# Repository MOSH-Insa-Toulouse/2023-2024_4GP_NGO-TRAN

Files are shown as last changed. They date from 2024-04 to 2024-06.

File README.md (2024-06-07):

# 2023-2024 : Capteur low-tech Graphite (Tan Anh Khoa NGO &amp; Le Duc Minh TRAN)

## SOMMAIRE
*** 
  - [Contexte](#contexte)
  - [Livrables](#livrables)
  - [Matériel nécessaire](#matériel-nécessaire)
  - [1. Simulation électronique du capteur sous LTSpice](#simulation-électronique-du-capteur-sous-ltspice)
  - [2. Design du PCB sous KiCad](#design-du-pcb-sous-kicad)
  - [3. Code arduino](#code-arduino)
  - [4. Application android APK sous MIT App Inventor](#application-android-apk-sous-mit-app-inventor)
  - [5. Réalisation du shield](#réalisation-du-shield)
  - [6. Banc de test](#banc-de-test)
  - [7. Datasheet](#datasheet)
  - [Contact](#contact) 

*** 

## Contexte
&nbsp;&nbsp;&nbsp;&nbsp;&nbsp;&nbsp;Dans le cadre de l'unité de formation "Du capteur au banc de test" dispensée en 4ème année du cursus Génie Physique à l'INSA Toulouse, notre équipe a conçu un dispositif de mesure de contrainte innovant. L'inspiration pour le capteur de ce dispositif provient de l'article scientifique "Pencil Drawn Strain Gauges and Chemiresistors on Paper" (Cheng-Wei Lin*, Zhibo Zhao*, Jaemyung Kim & Jiaxing Huang). Ce capteur, d'une simplicité remarquable, est constitué d'un morceau de papier sur lequel du graphite est appliqué à l'aide d'un crayon à papier. 

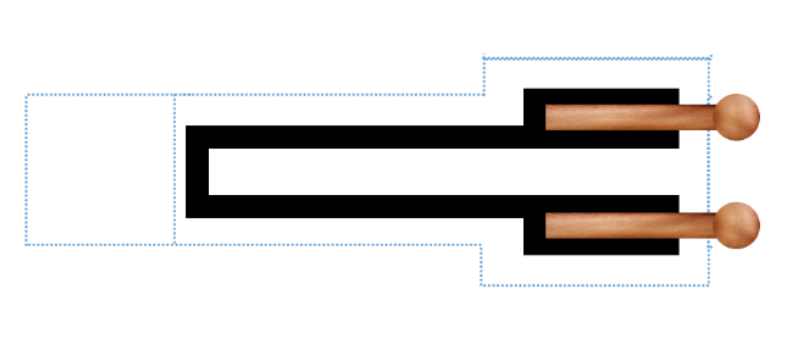
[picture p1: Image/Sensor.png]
capteur_graphite


&nbsp;&nbsp;&nbsp;&nbsp;&nbsp;&nbsp;Le principe de fonctionnement repose sur l'observation que la déformation du papier entraîne une variation du nombre de particules de graphite interconnectées. Cette modification de la structure granulaire du graphite se traduit par une variation de la résistance et de la conductance du capteur. En exploitant cette propriété, il devient possible de remonter à la déformation subie, à l'instar d'une jauge de contrainte classique.

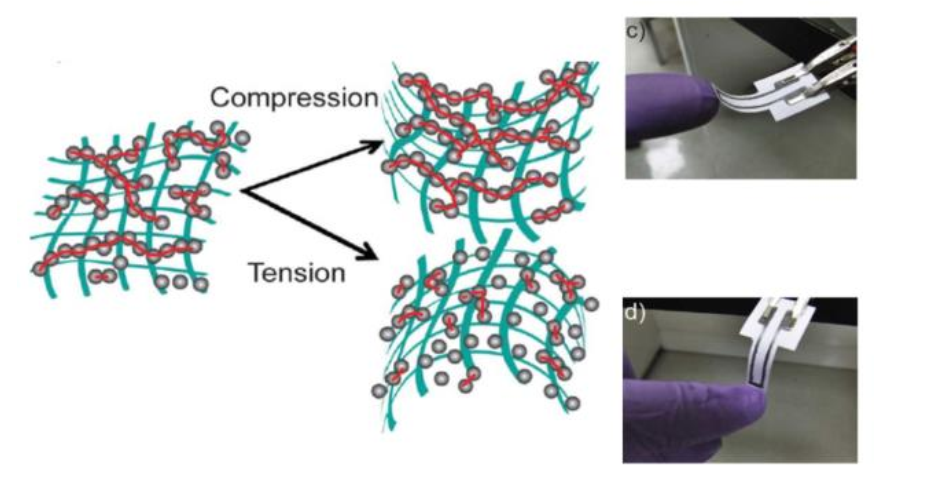
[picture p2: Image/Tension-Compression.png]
Tension-compression


&nbsp;&nbsp;&nbsp;&nbsp;&nbsp;&nbsp;Notre objectif principal était de développer un dispositif de mesure de déformation basé sur un capteur low-tech. Pour atteindre cet objectif, nous avons suivi une démarche structurée comprenant plusieurs étapes clés : simulations électroniques pour valider le concept, conception du circuit imprimé (PCB) pour intégrer le capteur, développement du code Arduino pour l'acquisition et le traitement des données, et enfin, réalisation de la fiche technique du dispositif.

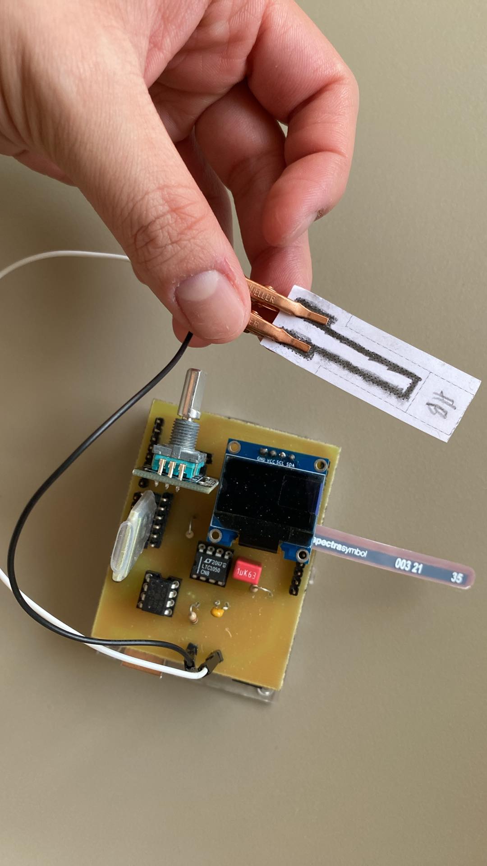
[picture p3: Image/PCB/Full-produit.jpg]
Full-produit


## Livrables
Les livrables de ce projet sont les suivants :
  
* Un shield PCB personnalisé connecté à une carte Arduino UNO. Ce shield intègre :
     
   - Un capteur de contrainte innovant à base de graphite.
   - Un amplificateur à transimpédance pour traiter le signal du capteur.
   - Un module Bluetooth pour la communication sans fil.
   - Un écran OLED pour l'affichage des données (ajouté pour améliorer l'expérience utilisateur).
   - Un capteur de flexion commercial pour comparaison (ajouté à des fins de validation).
   - Un potentiomètre numérique pour ajuster le gain de l'amplificateur (ajouté pour plus de flexibilité).
   - Un encodeur rotatif pour basculer entre les mesures des capteurs (ajouté pour faciliter la comparaison).
  
* Code Arduino     
   - L'acquisition des mesures de contrainte du capteur graphite.
   - La connexion et la communication Bluetooth.
   - L'affichage des données sur l'écran OLED.
   - Le réglage du gain via le potentiomètre numérique.
   - La sélection du capteur actif avec l'encodeur rotatif.
   - Réaliser des essais de banc de test rigoureux.
   - Évaluer les performances du capteur de contrainte graphite.
  
* Une application Android intuitive (APK) (développée avec MIT App Inventor) qui :
   - Permet de visualiser les données en temps réel.
   - Offre une interface conviviale pour interagir avec le système.

* Une datasheet complète qui détaille :
   - Les caractéristiques techniques du capteur graphite.
   - Son principe de fonctionnement.
   - Les instructions d'utilisation et de calibration.
   - Les résultats des tests de performance.

## Matériel nécessaire
Pour réaliser notre dispositif électronique, voici la liste des composants nécessaires :

- Résistances : 1 de 1 $k\ohm$, 1 de $10k\ohm$, 2 de $100k\ohm$ pour l'amplificateur transimpédance. 3 de $10k\ohm$ pour les boutons (peuvent être éviter en utilisant les résistances internes de l'arduino) et 1 de $33k\ohm$ pour le flex sensor.
- Capacités : 3 de 100 nF, 1 de 1 uF
- Arduino Uno
- Amplificateur opérationnel LTC1050
- Potentiomètre digital MCP41050
- Module Bluetooth HC05
- Ecran OLED 128x64
- Flex Sensor
- Encodeur rotatif KY-040

## Simulation électronique du capteur sous LTSpice
&nbsp;&nbsp;&nbsp;&nbsp;&nbsp;&nbsp;Pour amplifier le signal de notre capteur de graphite, caractérisé par une résistance élevée et un courant de sortie faible, nous avons conçu un montage à transimpédance. Ce montage, basé sur un amplificateur opérationnel (AOP), permet de convertir le faible courant en une tension exploitable par le convertisseur analogique-numérique (ADC) de l'Arduino UNO. \
&nbsp;&nbsp;&nbsp;&nbsp;&nbsp;&nbsp;La conception du circuit a été simulée sur LTspice, en suivant un [schéma spécifique](Image/LTspice/schema_suggere.png). Le choix de l'AOP s'est porté sur le LTC 1050, reconnu pour sa capacité à gérer des courants d'entrée faibles et son faible offset de tension, garantissant ainsi la précision des mesures. Voici son schéma :

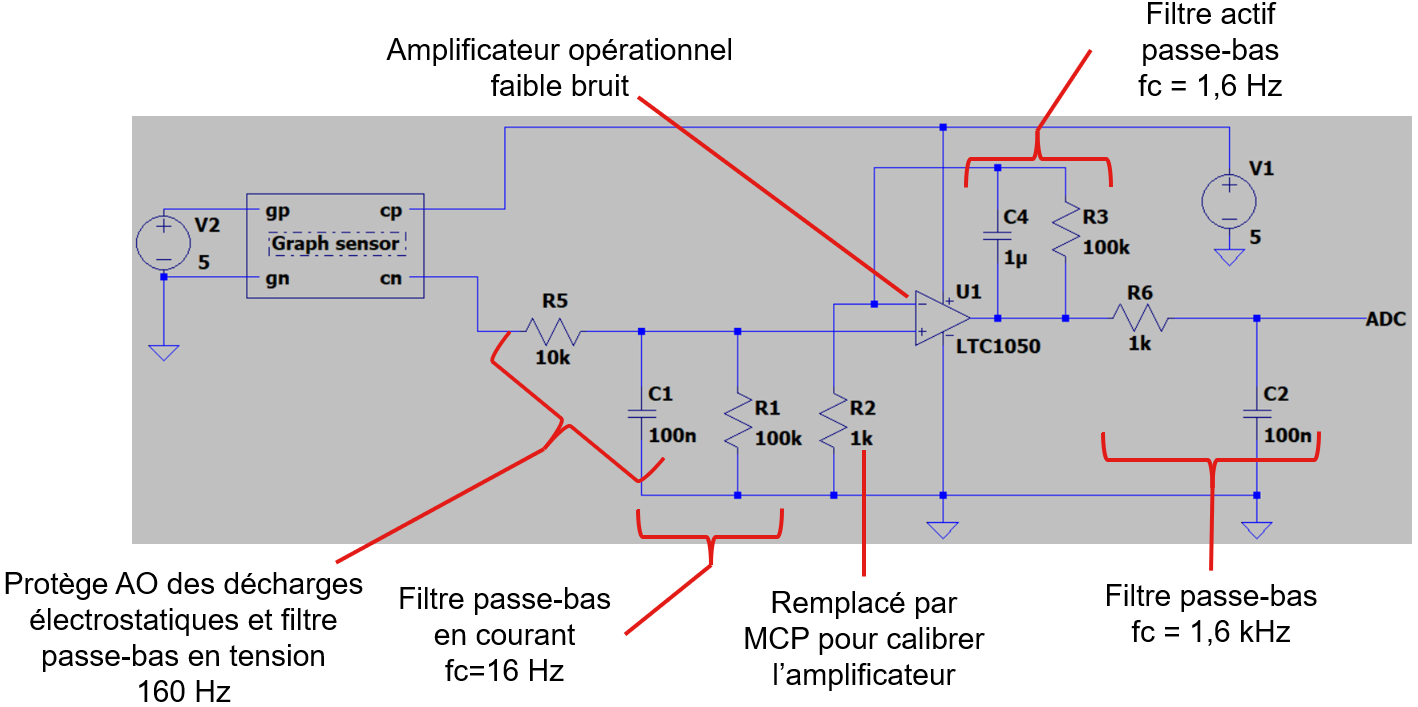
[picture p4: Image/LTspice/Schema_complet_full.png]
electronic-circuit


Afin d'optimiser la qualité du signal, trois filtres ont été intégrés au circuit :

- Un filtre passe-bas passif (R1, C1) à l'entrée, avec une fréquence de coupure de 16 Hz, pour atténuer les bruits en courant.
- Un filtre passe-bas actif (R3, C4) couplé à l'AOP, avec une fréquence de coupure de 1,6 Hz, pour filtrer le bruit à 50 Hz du réseau électrique.
- Un filtre passe-bas (R6, C2) à la sortie de l'AOP, avec une fréquence de coupure de 1,6 kHz, pour éliminer les bruits générés lors du traitement du signal.

De plus, des composants supplémentaires ont été ajoutés pour améliorer la robustesse du circuit :
- La capacité C3 pour filtrer le bruit de l'alimentation.
- La résistance R5 pour protéger l'AOP contre les décharges électrostatiques et former un filtre passe-bas avec C1 pour les bruits en tension.
- La résistance R2, qui sera remplacée par un potentiomètre numérique pour ajuster le gain de l'AOP selon les besoins.

Les tests effectués sur le circuit simulé ont confirmé l'efficacité des filtres.

Voici la réponse de notre circuit pour vérfier que le capteur soit correctement amplifié : 

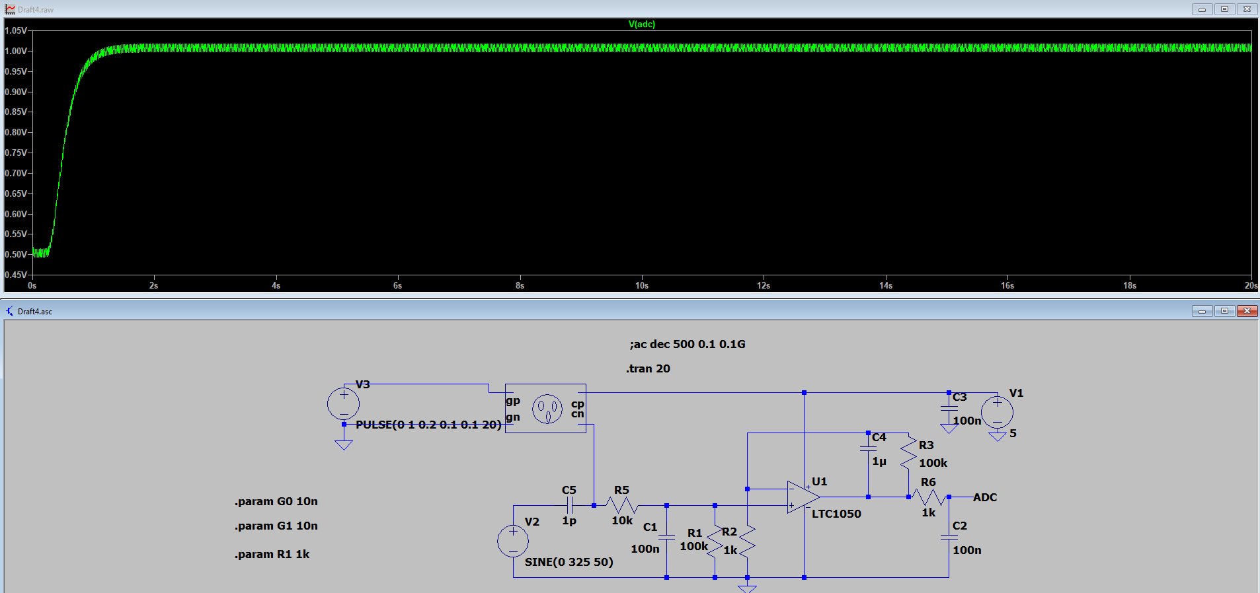
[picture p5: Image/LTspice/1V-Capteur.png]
Test_En_Transient

	
Le signal amplifié atteint 1V, une valeur compatible avec l'Arduino UNO.

De plus, la simulation d'un courant alternatif a démontré une atténuation significative du bruit, notamment une réduction d'environ 72 dB à 50 Hz.

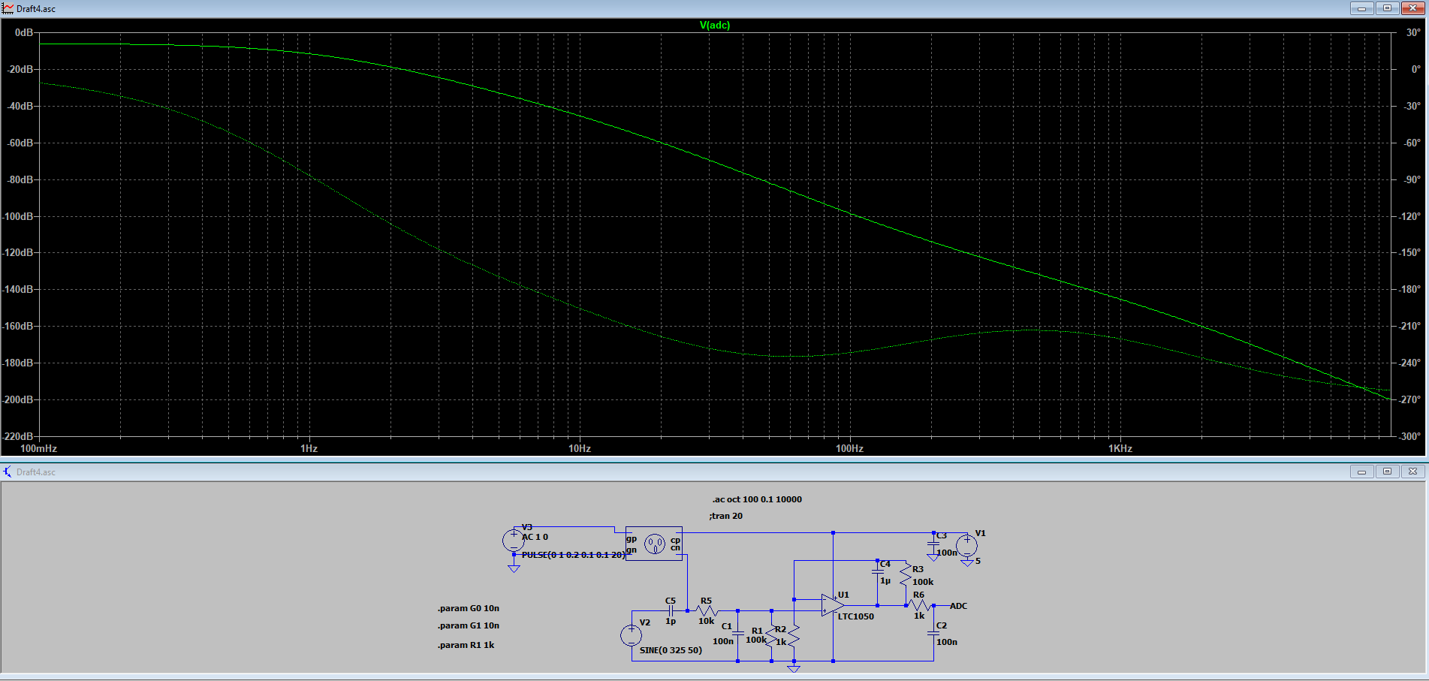
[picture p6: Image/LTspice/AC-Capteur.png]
Test_En_AC


## Design du PCB sous KiCad

Pour développer notre circuit imprimé (PCB), nous avons utilisé le logiciel KiCad 7.0 et avons reproduit le schéma électrique initial, en y apportant quelques modifications. La résistance R2 a été remplacée par un potentiomètre numérique pour permettre le réglage du gain de l'AOP.

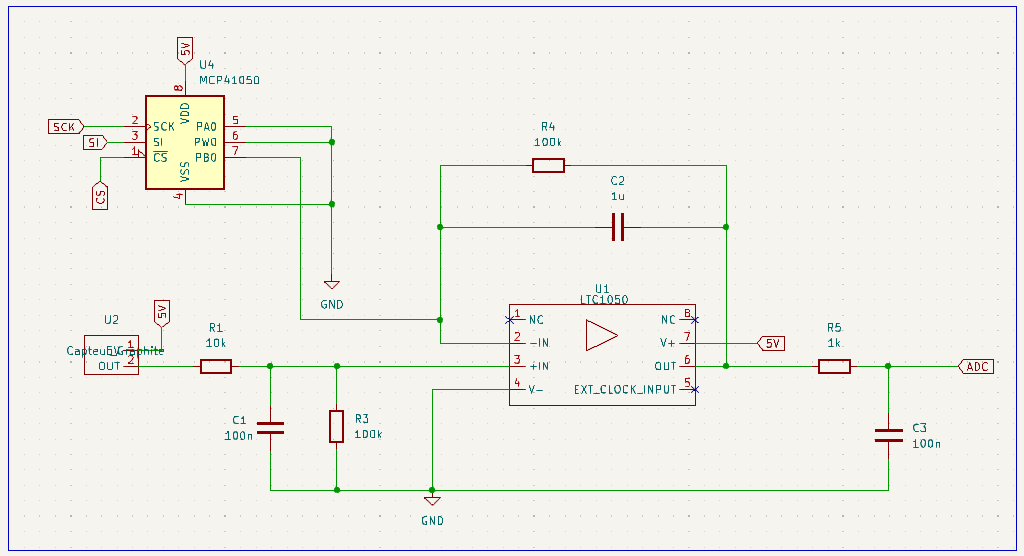
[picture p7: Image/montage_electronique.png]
transimpedence


Afin d'optimiser les capacités de mesure et de comparaison de notre capteur graphite, nous avons intégré plusieurs composants supplémentaires :

- GrapheSenso (notre capteur graphite) pour mesurer les variations de résistance.
- Un flex sensor commercial servant de référence pour comparer les résultats.

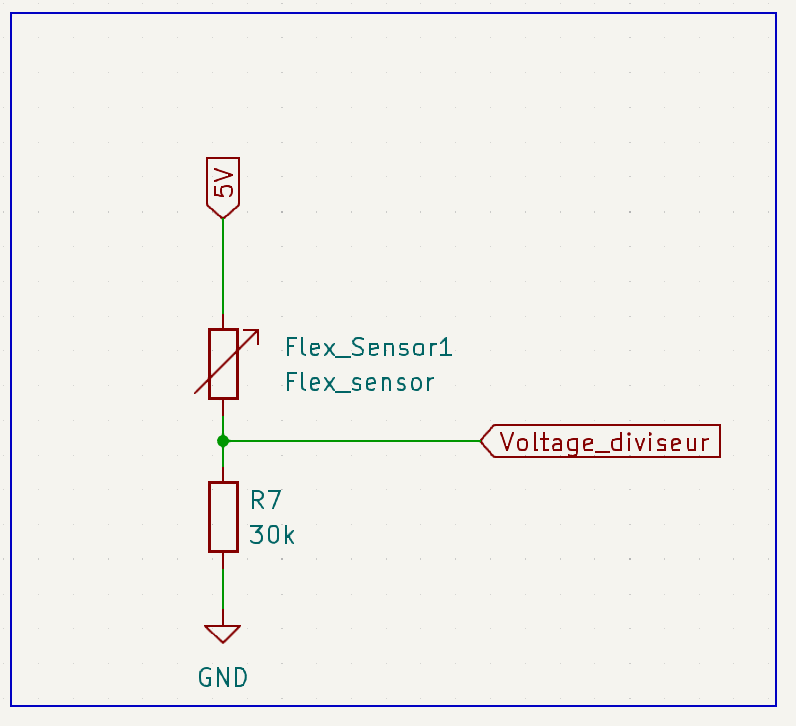
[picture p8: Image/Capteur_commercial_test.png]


- Un module Bluetooth HC-05 pour établir une communication sans fil avec une application mobile dédiée.
- Un écran OLED pour visualiser les mesures en temps réel.
- Un encodeur rotatif pour basculer facilement entre les deux capteurs dans l'interface de l'application.

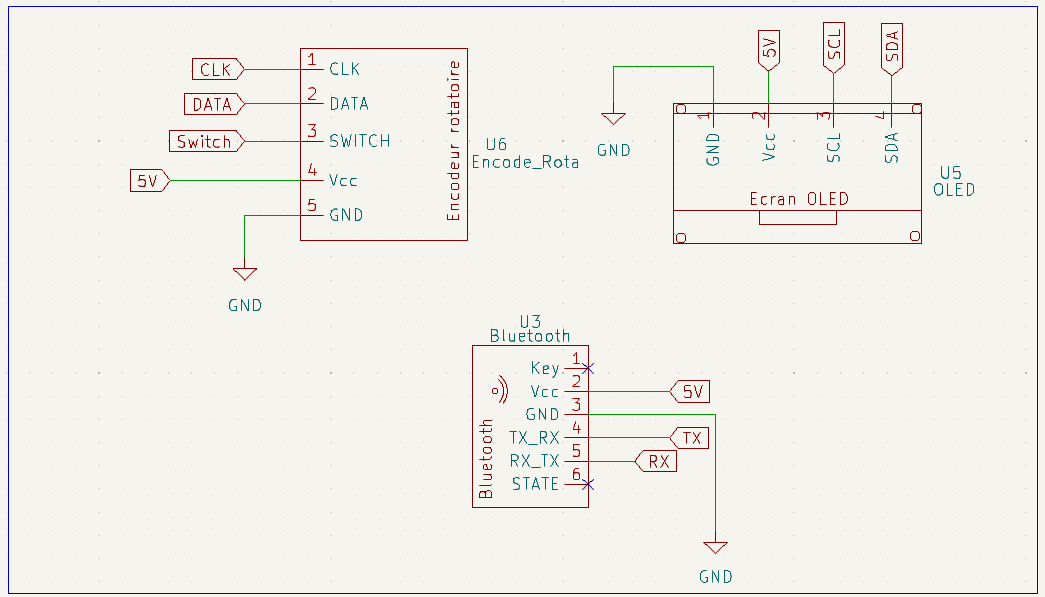
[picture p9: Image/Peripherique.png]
perpherique


Tous ces composants ont été soigneusement disposés sur un shield Arduino UNO pour faciliter l'intégration et l'utilisation.

La première étape de la conception du PCB a consisté à créer les symboles des différents composants et à reproduire le schéma électrique complet dans KiCad. Le schéma final intègre tous les éléments mentionnés ci-dessus.

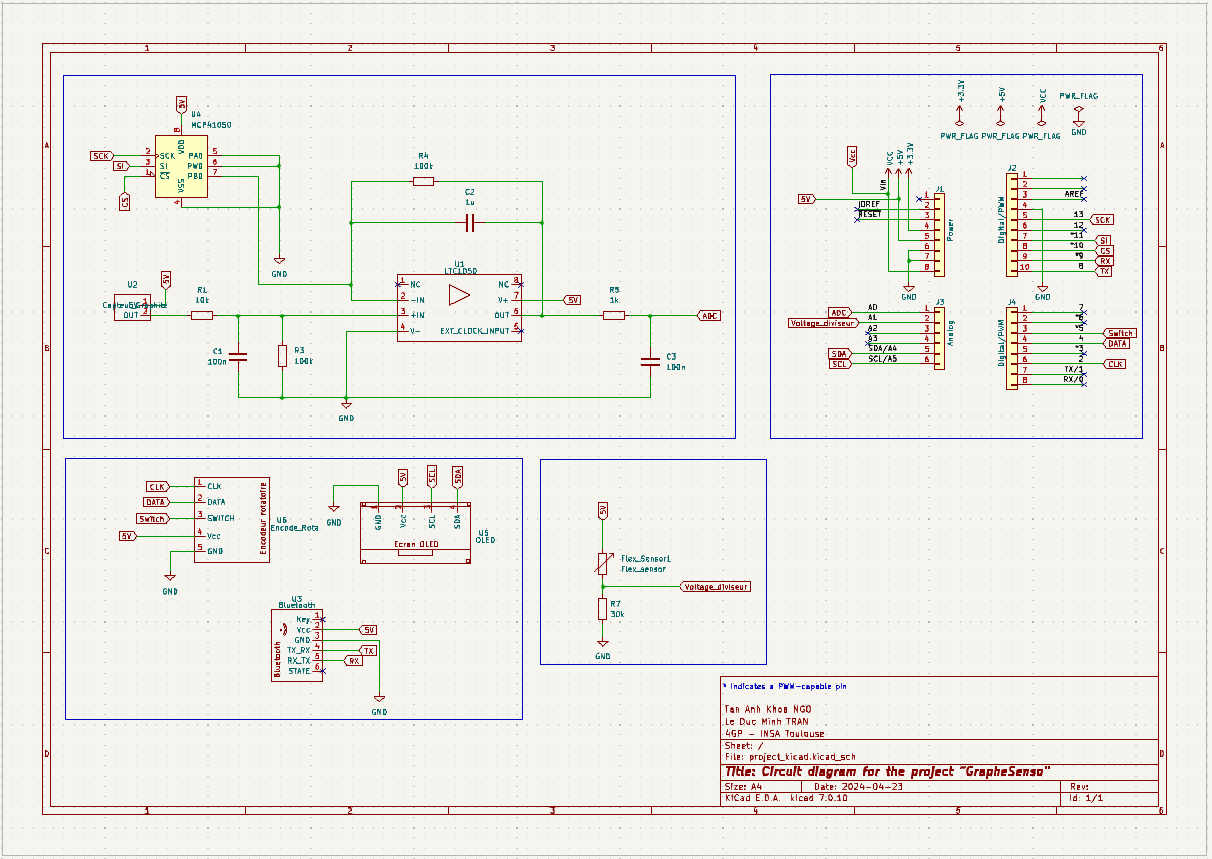
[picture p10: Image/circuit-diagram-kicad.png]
Schema_Kicad


Ensuite, nous avons réalisé les empreintes des composants pour les placer sur le PCB. L'un des défis majeurs a été d'optimiser le placement pour éviter les vias, en particulier pour la connexion à la masse (GND). Le résultat final est un PCB compact et fonctionnel.

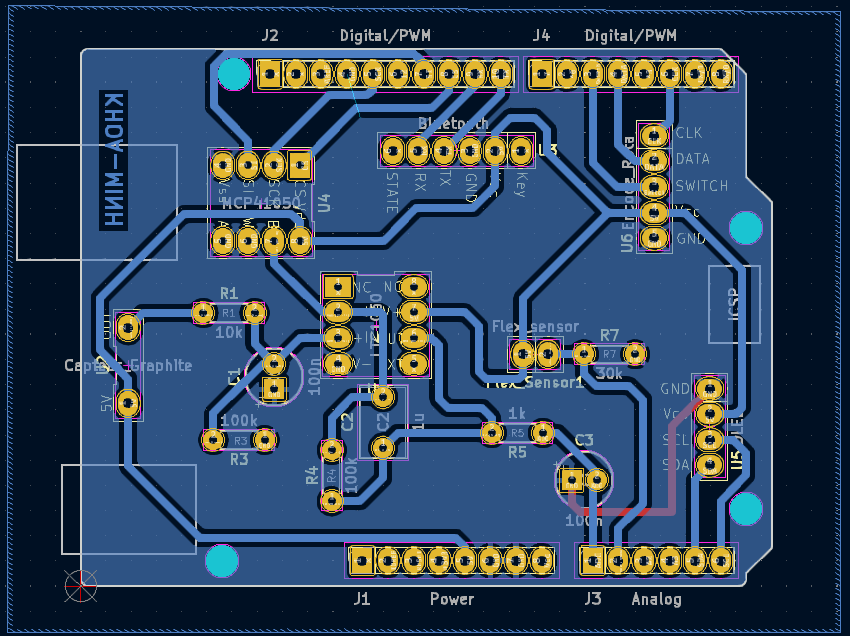
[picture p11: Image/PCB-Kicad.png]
PCB_Kicad


Une visualisation 3D du PCB a été générée pour vérifier le routage et l'agencement des composants. Cette étape a permis de s'assurer de la faisabilité de la fabrication du PCB.

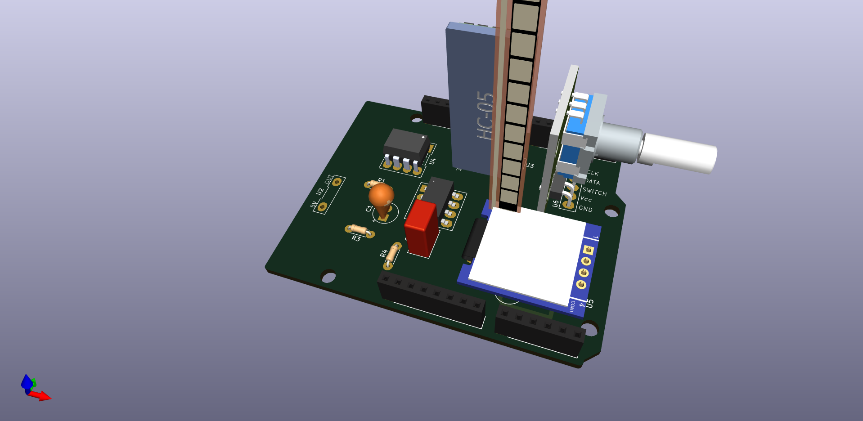
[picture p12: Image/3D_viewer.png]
3D_PCB_Kicad


Toutes les ressources utilisées pour la conception du PCB, y compris les empreintes, le schéma et les fichiers de conception, sont disponibles dans notre dossier KiCad.

## Code Arduino

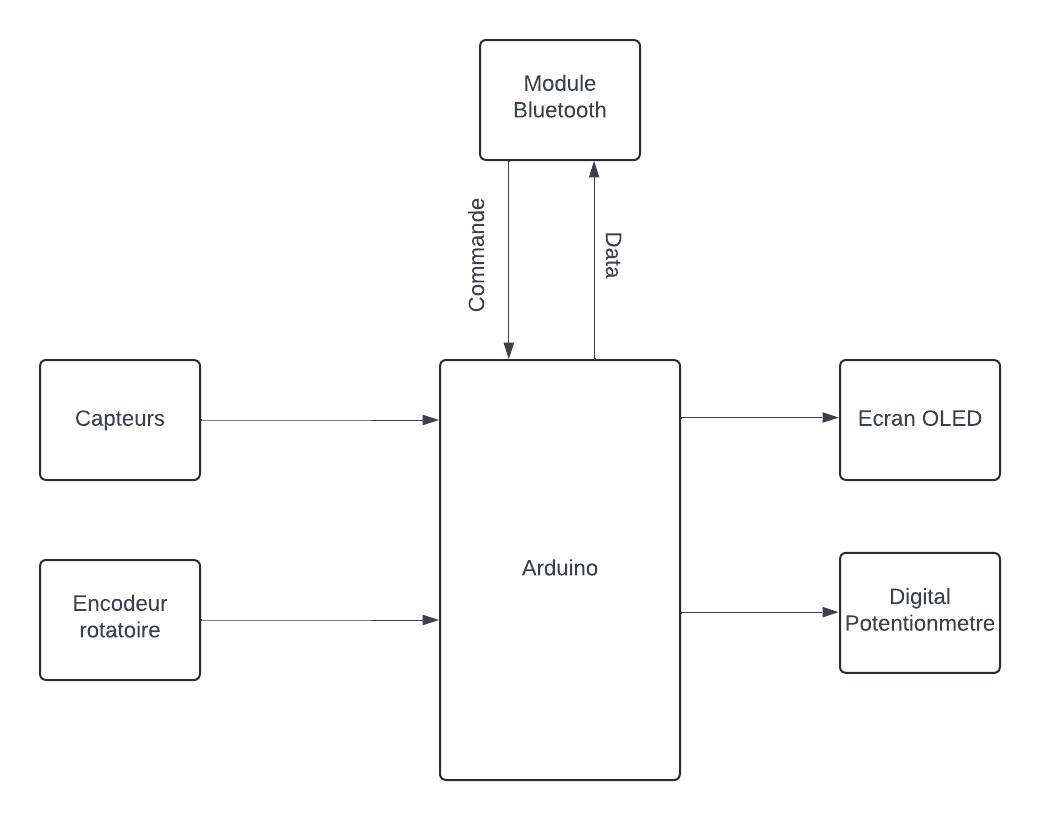
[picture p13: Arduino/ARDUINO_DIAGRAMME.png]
code

&nbsp;&nbsp;&nbsp;&nbsp;&nbsp;&nbsp;Notre [programme Arduino](Arduino/Projet_Capteur_Final.ino) permet de mesurer la résistance du capteur en graphène et du flex sensor en convertissant les valeurs de tension obtenues par l'ADC de l'Arduino. Les valeurs de résistance sélectionnées sont ensuite affichées sur l'écran OLED, la sélection étant contrôlée par l'encodeur rotatif.

&nbsp;&nbsp;&nbsp;&nbsp;&nbsp;&nbsp;Le programme établit également une communication bidirectionnelle entre le module Bluetooth et l'application mobile. Des protocoles spécifiques ont été mis en place pour gérer l'échange de données et de commandes. Le module Bluetooth reçoit les instructions de l'application mobile, telles que la demande de données ou le réglage de la résistance du potentiomètre numérique, et transmet les données mesurées en retour.

&nbsp;&nbsp;&nbsp;&nbsp;&nbsp;&nbsp;Une fonctionnalité notable de notre programme est la possibilité de régler le gain de l'amplificateur en modifiant la valeur de résistance du potentiomètre numérique via l'interface de l'application mobile. Cette flexibilité permet d'adapter le système à différentes conditions de mesure.

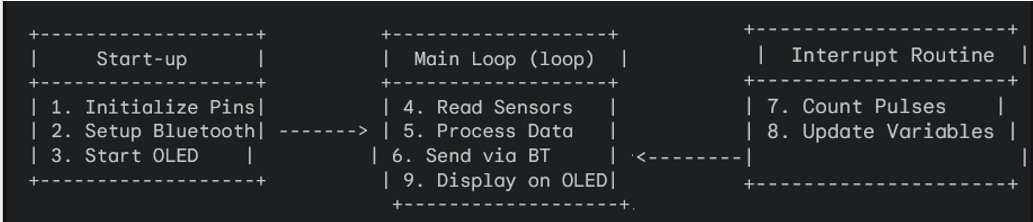
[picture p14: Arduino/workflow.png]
workflow


## Application android APK sous MIT App Inventor
&nbsp;&nbsp;&nbsp;&nbsp;&nbsp;&nbsp;Une application est également disponible avec le dispositif : développé sous [MIT App Inventor](https://appinventor.mit.edu/) . 

&nbsp;&nbsp;&nbsp;&nbsp;&nbsp;&nbsp;L'application reçoit les données transmis par le module bluetooth HC-05. Elle affiche ensuite la valeur tranmis (des $M\ohm$ pour le capteur graphite ou des $\ohm$ pour le flex sensor.

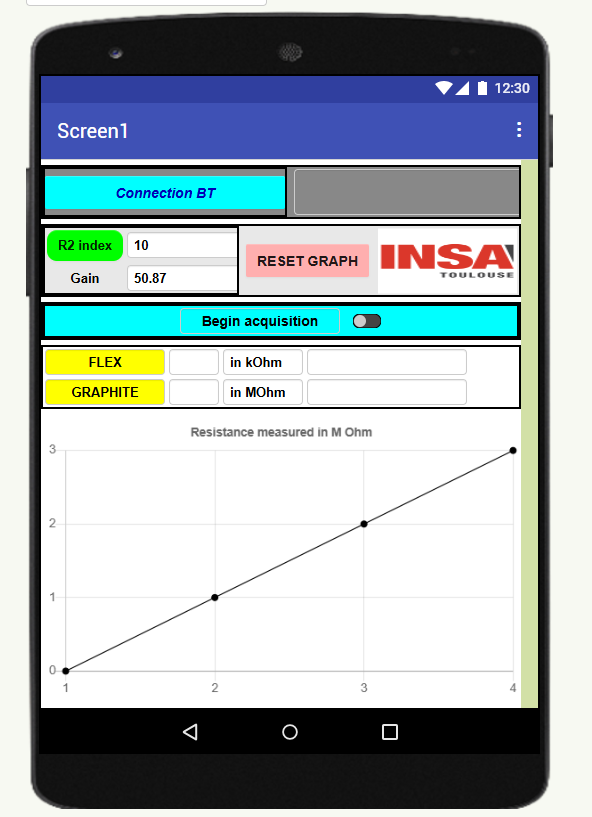
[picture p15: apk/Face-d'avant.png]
face-avant


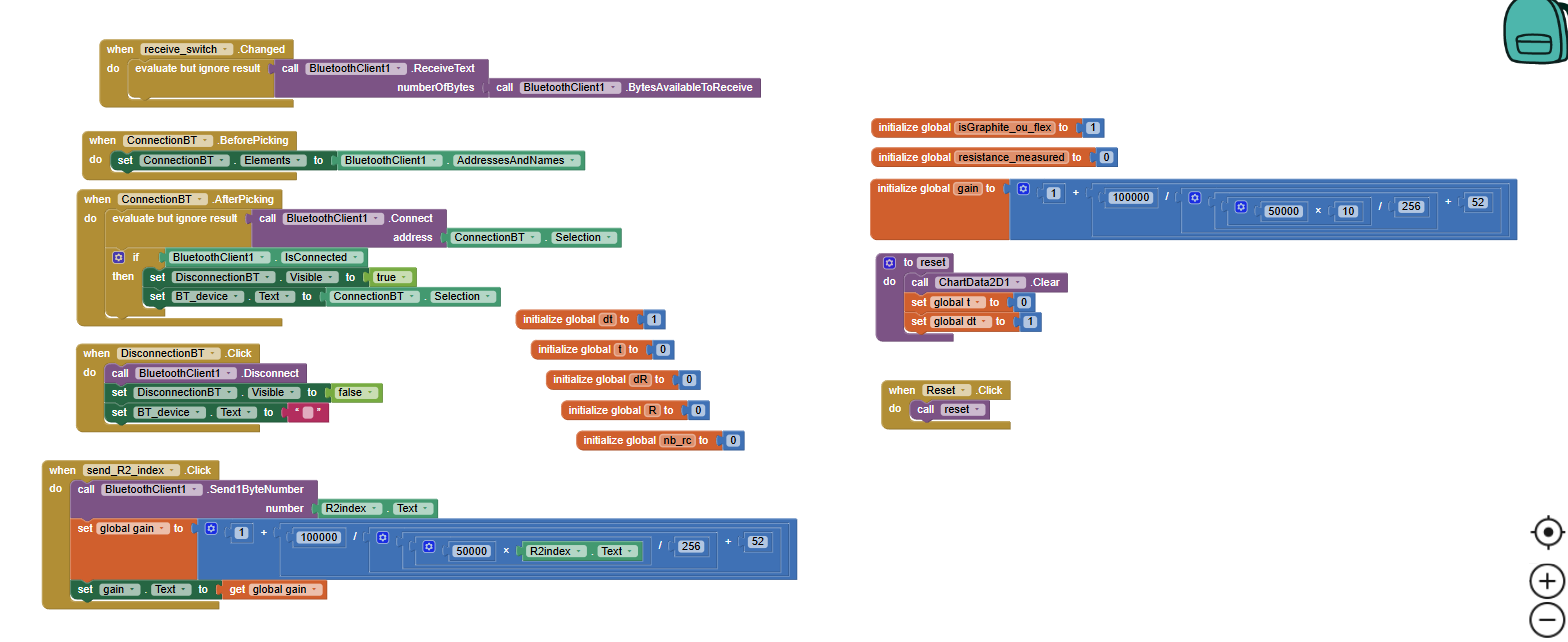
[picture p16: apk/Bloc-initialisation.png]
blocinitial

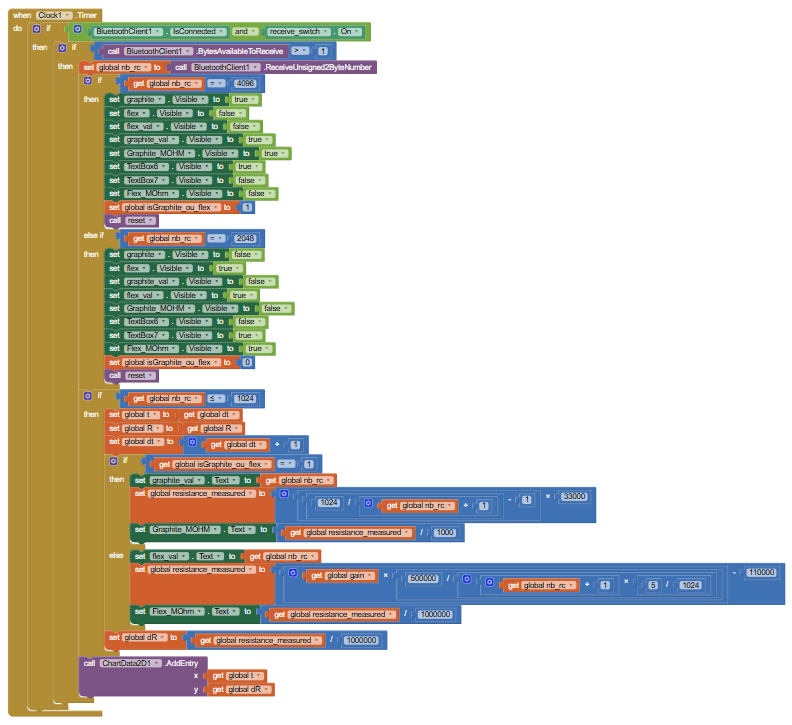
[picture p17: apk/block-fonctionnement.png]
blocfonctionnement


&nbsp;&nbsp;&nbsp;&nbsp;&nbsp;&nbsp;L'application peut s'installer [sous android ici](apk/First_application_copy.apk) et toutes les informations liées à l'application son dans [le dossier Application Android](apk).

### Résumé des particularités de nos programmes et applications
&nbsp;&nbsp;&nbsp;&nbsp;&nbsp;&nbsp;Nos programmes et applications se distinguent par une optimisation supérieure à celle d'autres projets. Nous utilisons 2 octets de données pour la transmission, préservant ainsi la résolution et simplifiant la programmation de l'encodeur rotatif, contrairement à d'autres projets qui utilisent 1 octet et sacrifient la résolution.

&nbsp;&nbsp;&nbsp;&nbsp;&nbsp;&nbsp;De plus, notre application développée sur la plateforme du MIT emploie la commande "read" pour vider le tampon avant la lecture des données, garantissant ainsi la fiabilité des données lues et l'affichage précis des graphiques.

## Réalisation du shield

&nbsp;&nbsp;&nbsp;&nbsp;&nbsp;&nbsp;Dans le cadre de notre projet, nous avons réalisé la fabrication d'un circuit imprimé (PCB) au sein des départements de Génie Électrique et Informatique et de Génie Physique de l'INSA Toulouse. Après avoir conçu le circuit sur le logiciel KICAD, nous avons confié l'impression à Cathy.

&nbsp;&nbsp;&nbsp;&nbsp;&nbsp;&nbsp;Le processus de fabrication a débuté par l'impression de notre modèle sur du papier calque, qui a ensuite servi de masque pour l'insolation UV d'une plaquette d'époxy cuivrée. L'exposition aux UV a duré une dizaine de minutes, après quoi la résine non exposée a été éliminée à l'aide d'un révélateur. La plaquette a ensuite été plongée dans un bain de perchlorure de fer pendant 7 à 9 minutes pour dissoudre le cuivre non protégé, révélant ainsi les pistes du circuit. Un rinçage à l'acétone a finalisé le processus, nous permettant d'obtenir un PCB conforme à notre conception initiale.

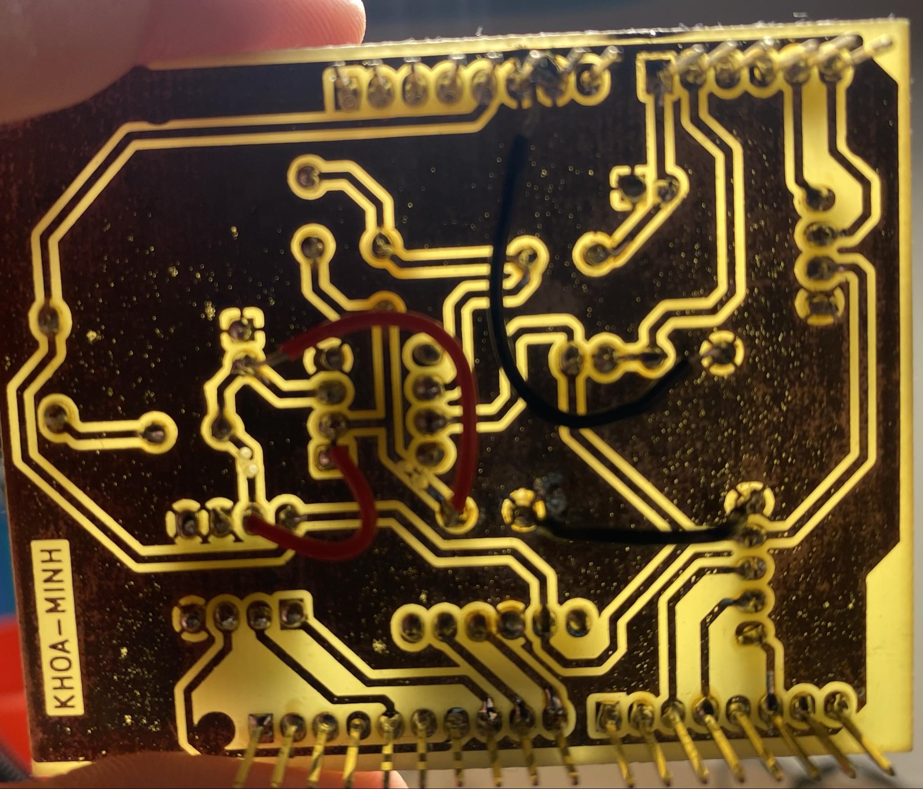
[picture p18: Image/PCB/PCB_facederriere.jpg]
Image du processus de fabrication du PCB


&nbsp;&nbsp;&nbsp;&nbsp;&nbsp;&nbsp;Une fois le PCB fabriqué, nous avons procédé à son assemblage. Cela a nécessité le perçage de trous de deux tailles différentes, 0,8 mm et 1 mm, selon les spécifications de notre projet KICAD. Les trous de 0,8 mm ont été utilisés pour les composants tels que les AOP LTC1050, les résistances et les condensateurs, tandis que les trous de 1 mm ont servi pour les broches de connexion de l'Arduino Uno et les headers des modules OLED, Bluetooth et encodeur rotatif. Après le perçage, nous avons soudé les composants en place à l'aide d'étain pour garantir des connexions électriques solides.

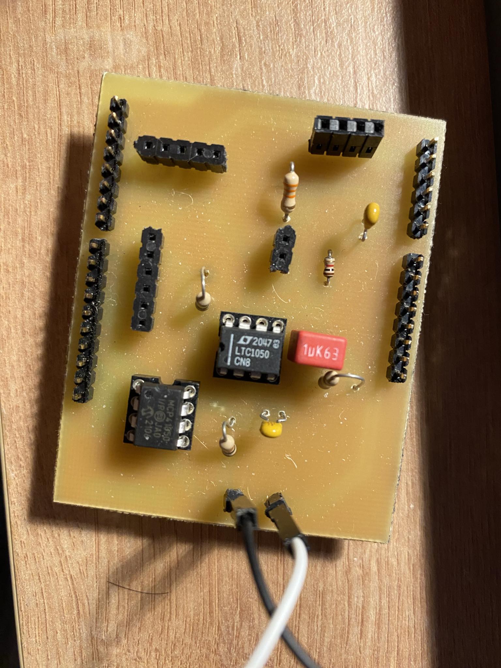
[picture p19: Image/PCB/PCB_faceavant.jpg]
Face du PCB


&nbsp;&nbsp;&nbsp;&nbsp;&nbsp;&nbsp;Nous tenons à remercier chaleureusement Cathy pour son aide précieuse dans la réalisation de notre PCB. Son expertise et son soutien ont été essentiels pour mener à bien cette étape cruciale de notre projet.

PCB-final

## Banc de test

&nbsp;&nbsp;&nbsp;&nbsp;&nbsp;&nbsp;Afin de caractériser notre capteur et son montage transimpédance, nous avons opté pour des demi-cercles imprimés en 3D de diamètres croissants (de 2 cm à 5 cm par incréments de 0,5 cm). Cette configuration nous permet d'évaluer l'évolution de la résistance électrique en fonction de la déformation appliquée.

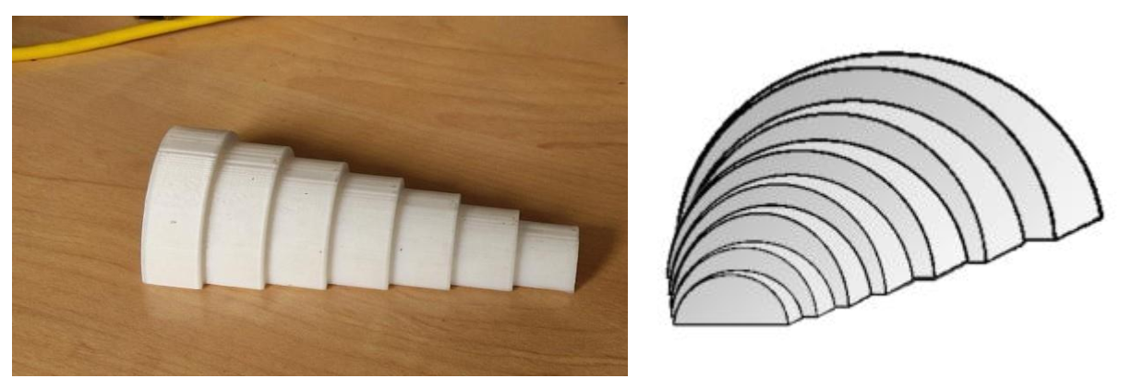
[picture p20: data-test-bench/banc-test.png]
Image Banc de Test


&nbsp;&nbsp;&nbsp;&nbsp;&nbsp;&nbsp; Grâce à ces demis-cercles, nous allons pouvoir calculer la variation de la résistance électrique $\frac{\Delta R}{R_0}$ en fonction de la déformation $\epsilon=\frac{e}{D}$. Nous avons ici mesuré notre épaisseur de notre papier $e=0.2 mm$. ALes mesures effectuées sur papier d'épaisseur constante (0,1 mm pour le plus petit diamètre, 0,04 mm pour le plus grand) révèlent des courbes caractéristiques distinctes pour les crayons 2B, B et HB, en tension comme en compression.

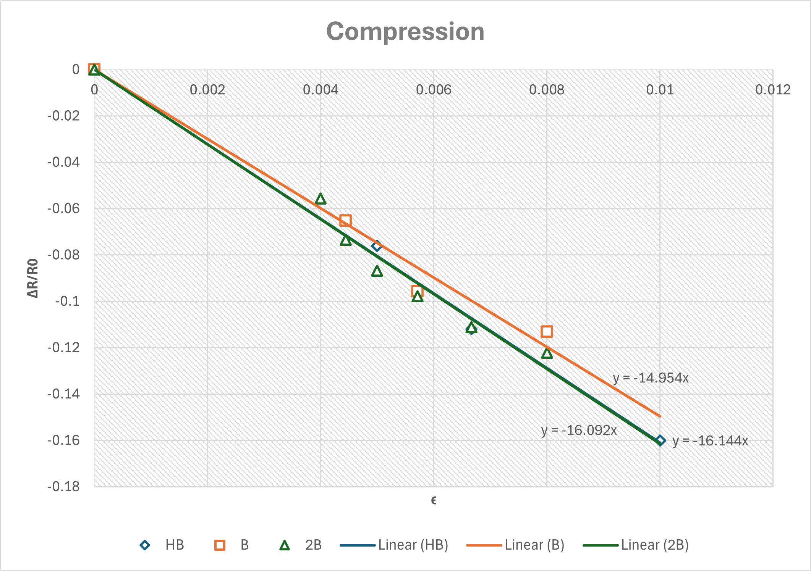
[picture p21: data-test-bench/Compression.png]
Compression


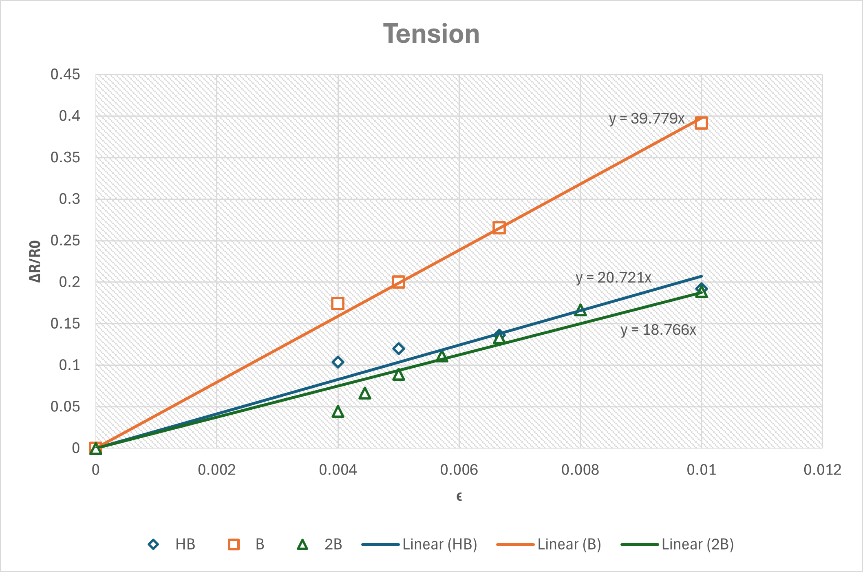
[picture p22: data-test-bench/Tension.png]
Tension


&nbsp;&nbsp;&nbsp;&nbsp;&nbsp;&nbsp;Nous observons une augmentation de la résistance en tension (éloignement des atomes de carbone) et une diminution en compression (rapprochement des atomes). De plus, la variation relative de résistance est inversement proportionnelle à la quantité de carbone présente dans le crayon (2H < H < HB < B < 2B).

&nbsp;&nbsp;&nbsp;&nbsp;&nbsp;&nbsp;Contrairement aux travaux de Cheng-Wei Lin et al. ("Pencil Drawn Strain Gauges and Chemiresistors on Paper"), nous avons réussi à mesurer la résistance avec un crayon 2H.

&nbsp;&nbsp;&nbsp;&nbsp;&nbsp;&nbsp;En comparaison avec un capteur de flexion commercial, notre dispositif semble moins sensible et moins résistant aux fortes déformations, limitant son nombre d'utilisations, cependant, ils peuvent être utilisés dans deux directions, ce qui constitue une nette amélioration par rapport aux capteurs commerciaux utilisés dans une seule direction.

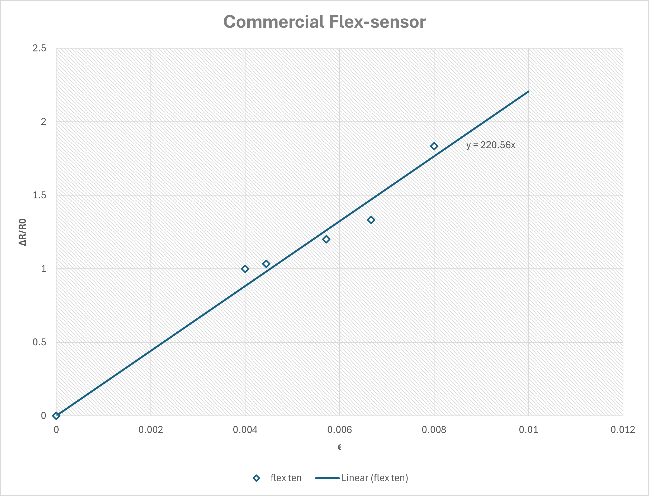
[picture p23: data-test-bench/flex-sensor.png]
flex-sensor


&nbsp;&nbsp;&nbsp;&nbsp;&nbsp;&nbsp;Il est important de noter que ces résultats sont à interpréter avec prudence, compte tenu des conditions expérimentales variables (quantité de graphite déposée, méthode de déformation).

&nbsp;&nbsp;&nbsp;&nbsp;&nbsp;&nbsp;Pour améliorer la reproductibilité, nous recommandons l'utilisation d'un servo-moteur pour contrôler précisément la déformation et la quantité de graphite déposée. Alternativement, des cercles de diamètres connus pourraient être reproduits avec des déformations plus faibles pour préserver l'intégrité du capteur.

## Datasheet

&nbsp;&nbsp;&nbsp;&nbsp;&nbsp;&nbsp; Vous pouvez retrouver la datasheet du produit [ici](datasheet/Datasheet-GrapheSenso.pdf).

## Contact

&nbsp;&nbsp;&nbsp;&nbsp;&nbsp;&nbsp;Vous pouvez nous contacter pour toutes questions :
- Tan Anh Khoa NGO : takngo@insa-toulouse.fr
- Le Duc Minh TRAN : ltra@insa-toulouse.fr

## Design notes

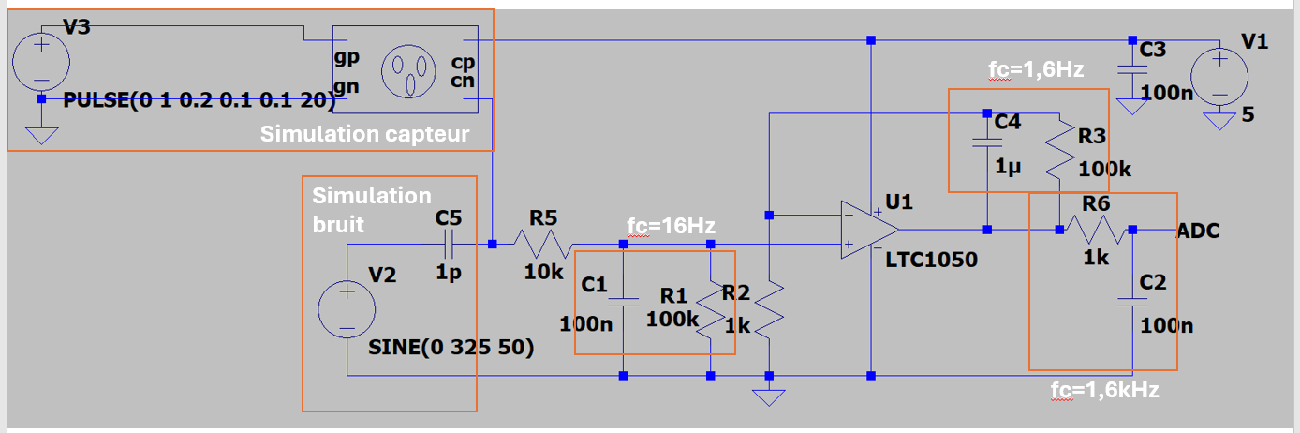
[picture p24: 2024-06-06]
Image/LTspice/Schema_complet.png

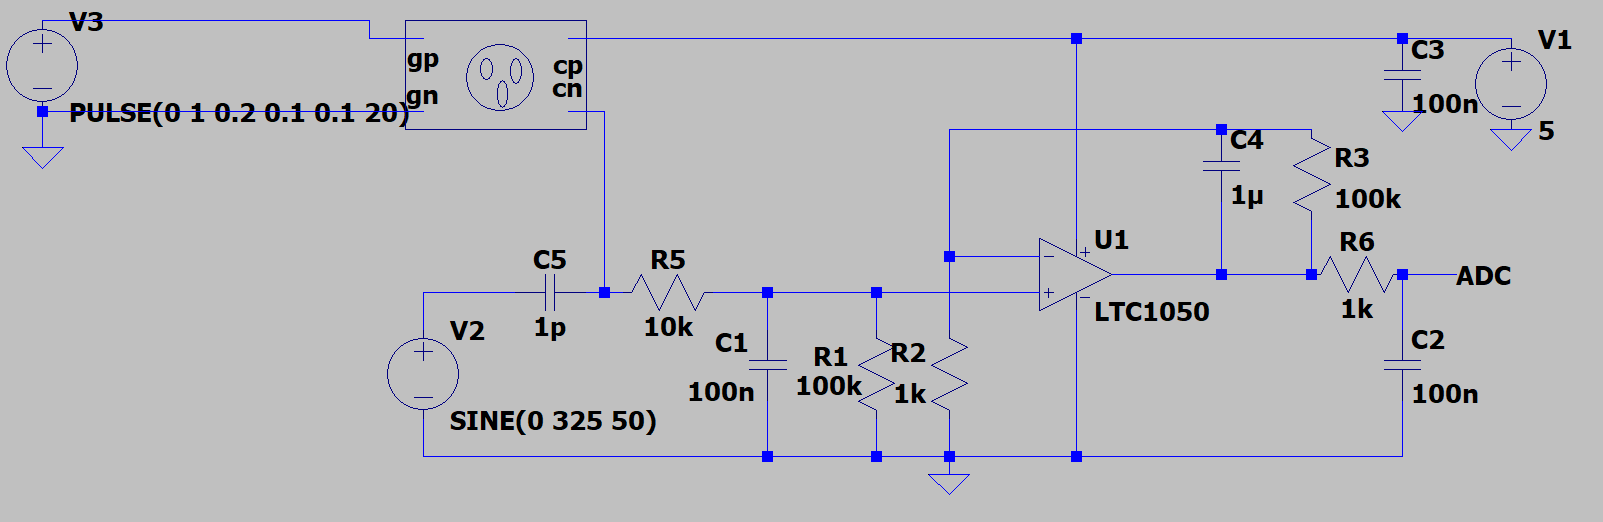
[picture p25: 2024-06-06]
Image/LTspice/Schema.png

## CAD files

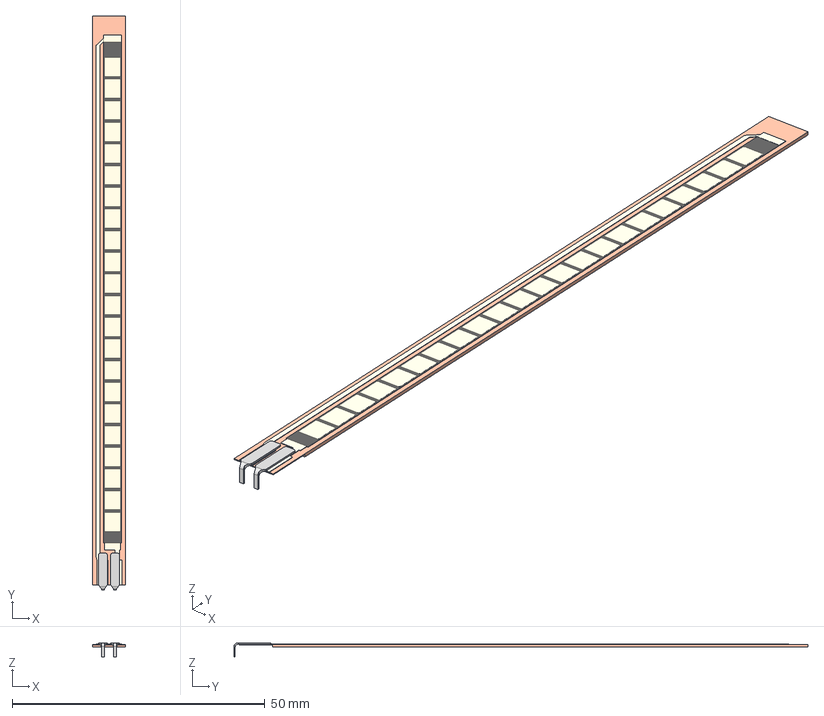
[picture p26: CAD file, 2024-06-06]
KICAD/flex-sensor-fs-l-0095-103-st-1.snapshot.2/FS-L-0095-103-ST - Assembly.stp
6.45 x 113.5 x 2.77 mm
FS-L-0095-103-ST - Base
FS-L-0095-103-ST - Top

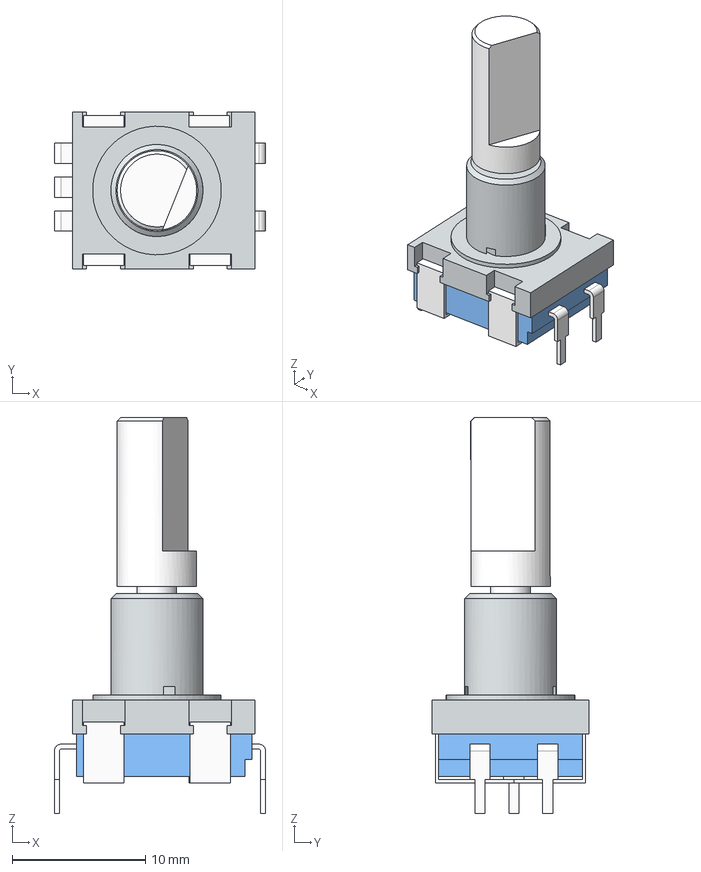
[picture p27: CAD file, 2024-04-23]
KICAD/rotary-encoder-1.snapshot.8/rotary encoder step files/Step Files/Rotary Encoder without pcb Assembly.stp
15.8 x 11.8 x 29.7 mm
mtg flange
body_encoder
pins_encoder body_2 x 5
shaft_encoder

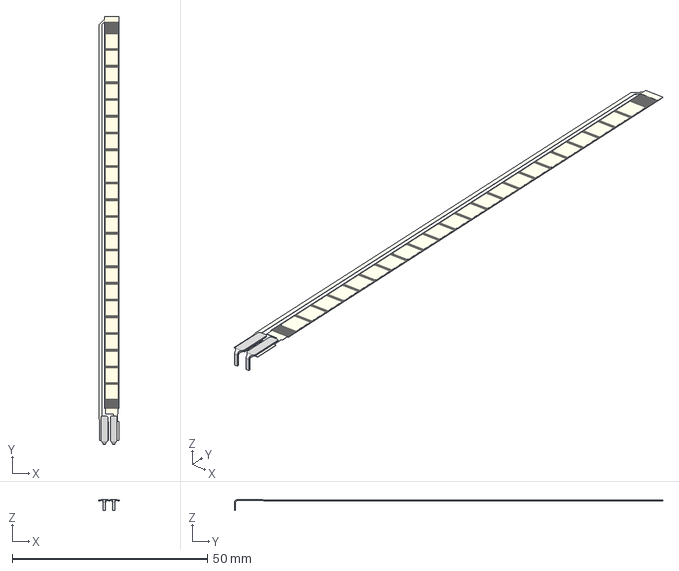
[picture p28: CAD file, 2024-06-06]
KICAD/flex-sensor-fs-l-0095-103-st-1.snapshot.2/SolidEdge/FS-L-0095-103-ST - Top - Right.stp
5.17 x 109.7 x 2.77 mm

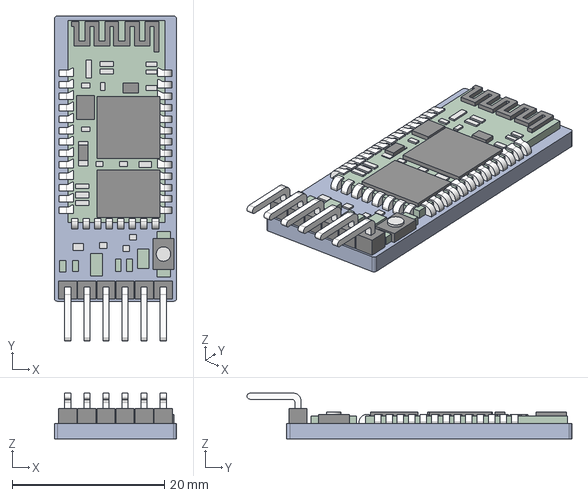
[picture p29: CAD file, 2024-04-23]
KICAD/hc-05-bluetooth-module-2.snapshot.1/HC_05 Blue Tooth Module.stp
16.1 x 42.7 x 6.00 mm

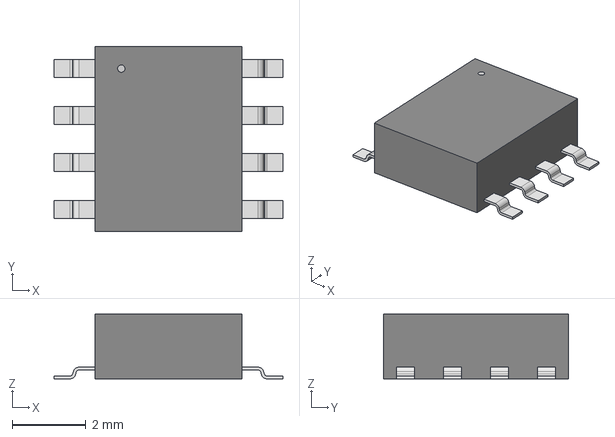
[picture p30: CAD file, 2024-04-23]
KICAD/LTC1050CS8_PBF/SO-8_S_LIT.step
6.20 x 5.00 x 1.75 mm

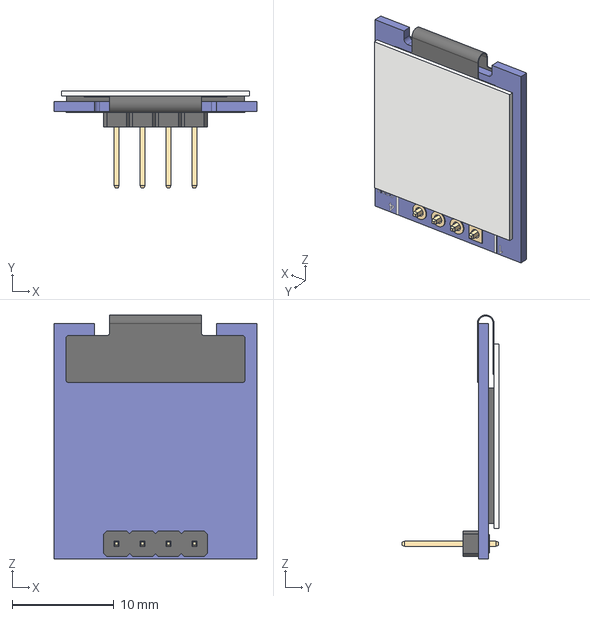
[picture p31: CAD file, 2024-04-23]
KICAD/oled-64x48-display-module-mdob064048av-wi-1.snapshot.1/OLED 64x48 Display Module - MDOB064048AV-WI/Model/OLED 64x48.step
19.9 x 9.55 x 23.9 mm

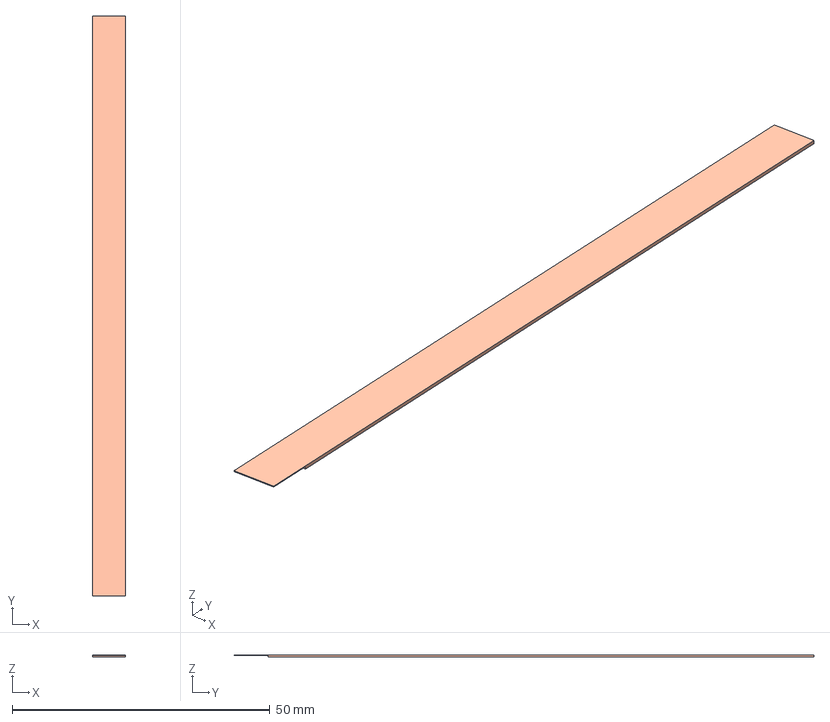
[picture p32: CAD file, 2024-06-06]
KICAD/flex-sensor-fs-l-0095-103-st-1.snapshot.2/SolidEdge/FS-L-0095-103-ST - Base.stp
6.45 x 112.4 x 0.483 mm

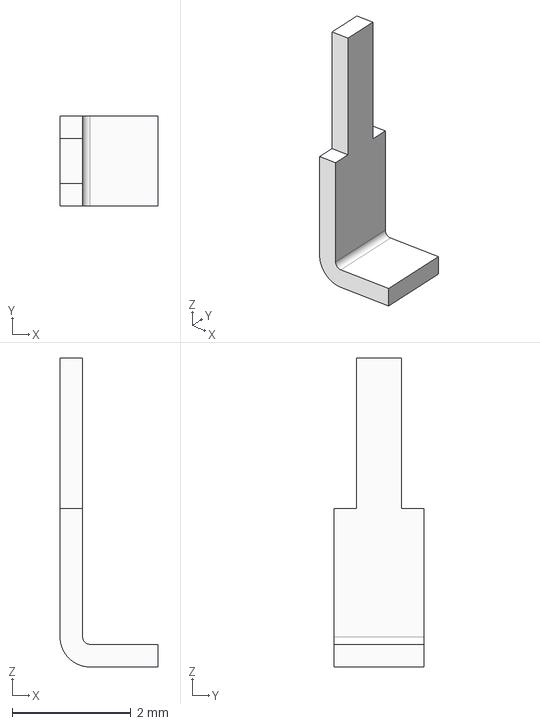
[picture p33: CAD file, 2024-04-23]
KICAD/rotary-encoder-1.snapshot.8/rotary encoder step files/Step Files/pins_encoder body_2.stp
1.65 x 1.52 x 5.21 mm

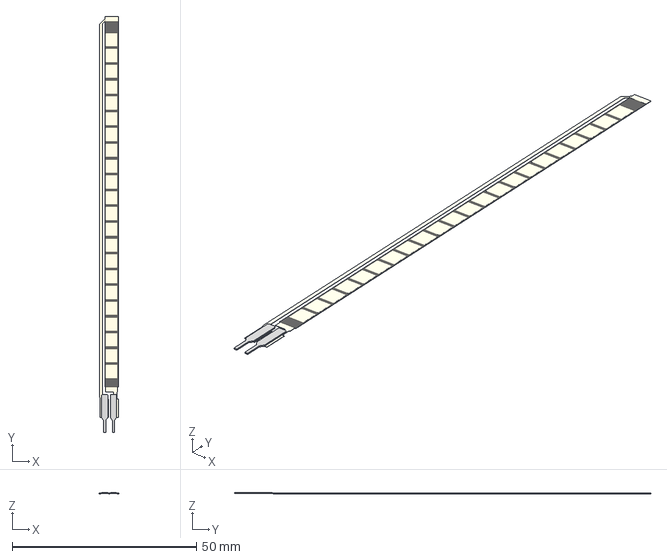
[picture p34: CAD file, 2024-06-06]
KICAD/flex-sensor-fs-l-0095-103-st-1.snapshot.2/SolidEdge/FS-L-0095-103-ST - Top.stp
5.17 x 112.8 x 0.292 mm

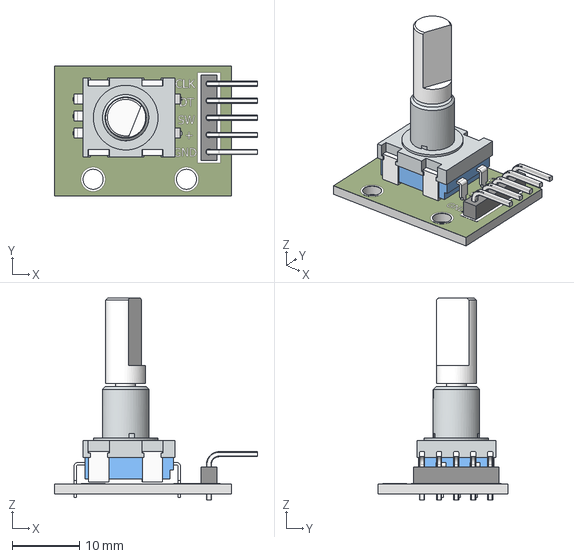
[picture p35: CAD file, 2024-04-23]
KICAD/rotary-encoder-1.snapshot.8/rotary encoder step files/Step Files/rotary encoder_chesr_2013.stp
30.3 x 19.3 x 30.1 mm

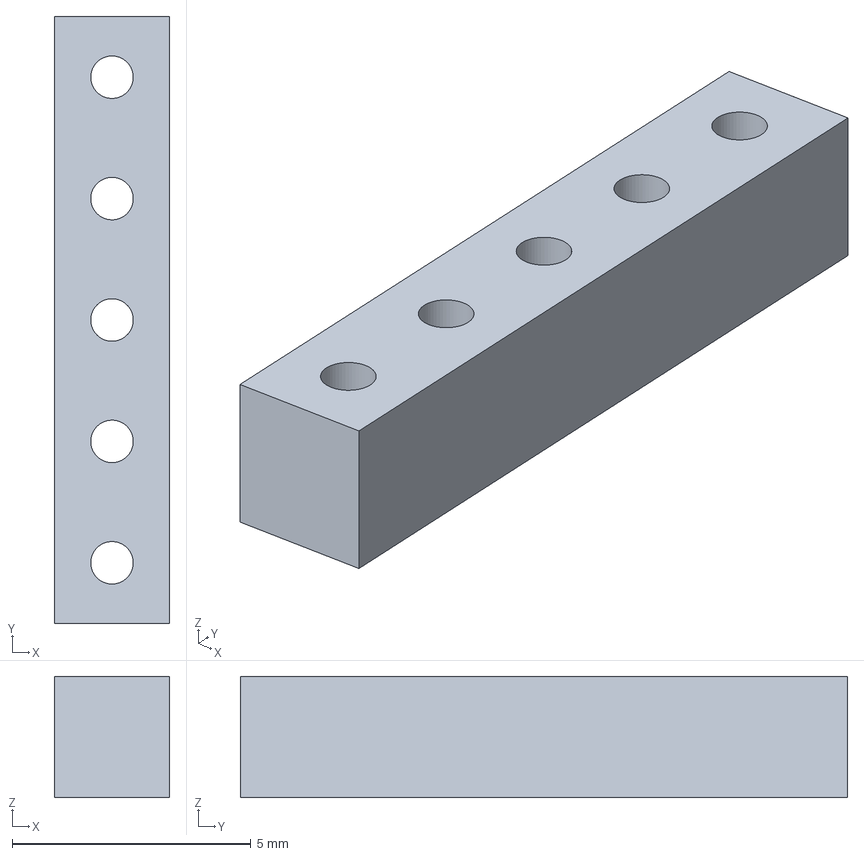
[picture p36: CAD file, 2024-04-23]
KICAD/rotary-encoder-1.snapshot.8/rotary encoder step files/Step Files/5 pin header.stp
2.41 x 12.7 x 2.54 mm

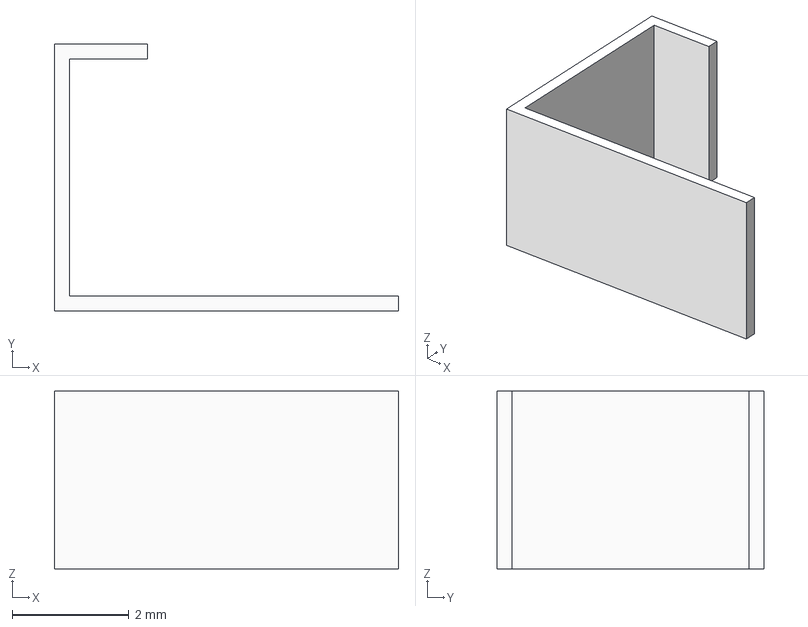
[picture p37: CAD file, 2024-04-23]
KICAD/rotary-encoder-1.snapshot.8/rotary encoder step files/Step Files/body_2.stp
5.89 x 4.57 x 3.05 mm

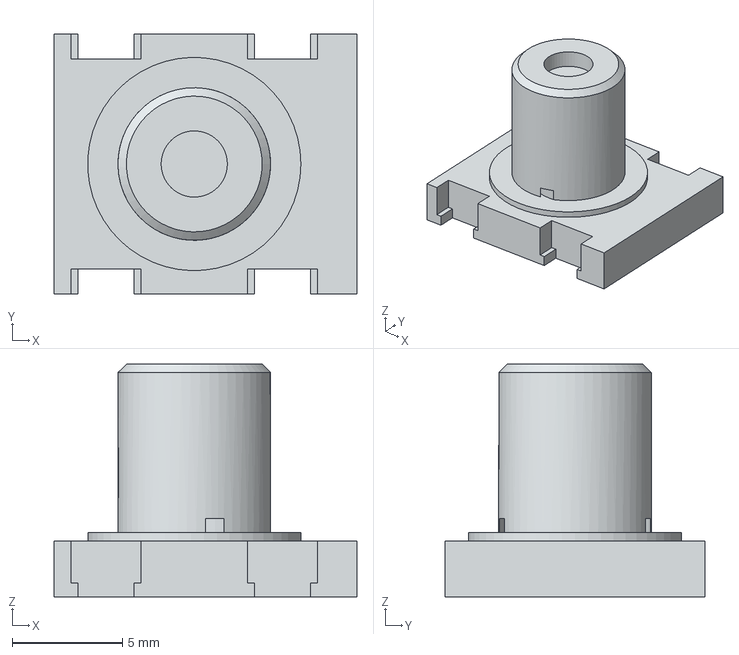
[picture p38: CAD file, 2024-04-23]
KICAD/rotary-encoder-1.snapshot.8/rotary encoder step files/Step Files/mtg flange.stp
13.7 x 11.8 x 10.5 mm

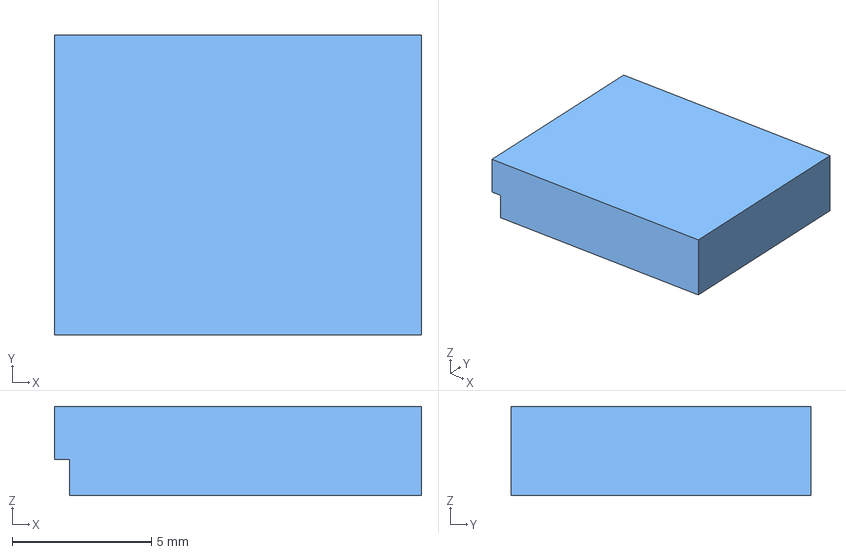
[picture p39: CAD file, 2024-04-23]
KICAD/rotary-encoder-1.snapshot.8/rotary encoder step files/Step Files/body_encoder.stp
13.2 x 10.8 x 3.20 mm

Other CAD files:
KICAD/rotary-encoder-1.snapshot.8/rotary encoder step files/Step Files/90d pin_header.stp
KICAD/rotary-encoder-1.snapshot.8/rotary encoder step files/Step Files/decal_encoder.stp
KICAD/rotary-encoder-1.snapshot.8/rotary encoder step files/Step Files/pcb.stp
KICAD/MCP41050_E_P(1)/MCP41050-E_P.step
KICAD/hc-05-bluetooth-module-2.snapshot.1/HC_05 Blue Tooth Module.ipt
KICAD/oled-64x48-display-module-mdob064048av-wi-1.snapshot.1/OLED 64x48 Display Module - MDOB064048AV-WI/Model/OLED 64x48.f3d
KICAD/oled-64x48-display-module-mdob064048av-wi-1.snapshot.1/OLED 64x48 Display Module - MDOB064048AV-WI/Model/OLED 64x48.obj
KICAD/rotary-encoder-1.snapshot.8/Rotary Encoder/5 pin header.ipt
KICAD/rotary-encoder-1.snapshot.8/Rotary Encoder/90d pin_header.ipt
KICAD/rotary-encoder-1.snapshot.8/Rotary Encoder/OldVersions/mtg flange.0001.ipt
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

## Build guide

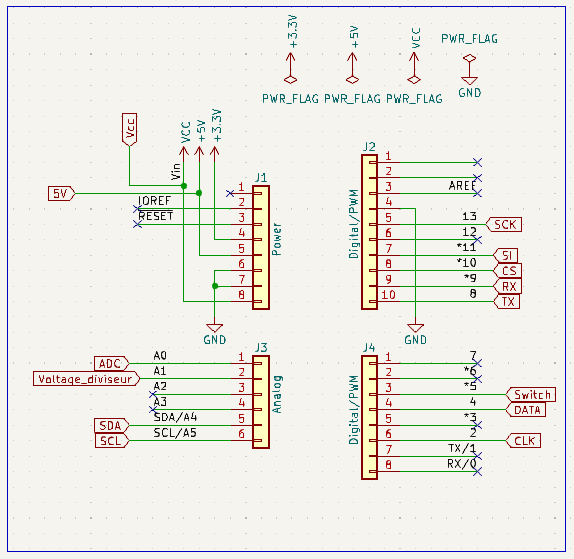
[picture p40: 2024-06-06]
Image/montage_arduino_uno.png

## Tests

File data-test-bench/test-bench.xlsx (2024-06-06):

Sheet: Sheet1
2B | Flat | stetch | bench
0 | 4.5
1 |  | 5.35
2 |  | 5.25 | 3.95
3 |  | 5.1 | 4
4 |  | 5 | 4.06
5 |  | 4.9 | 4.11
6 |  | 4.8 | 4.17
7 |  | 47000000 | 4.25

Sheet: Sheet2
HB | Flat | stetch | bench
0 | 2.5
1 |  | 2.98 | 2.1
2 |  | 0 | 0
3 |  | 2.84 | 2.22
4 |  | 0 | 0
5 |  | 2.8 | 2.31
6 |  | 0 | 0
7 |  | 2.76 | 0

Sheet: Sheet3
flex | Flat | stetch | bench
0 | 30
1 |  | 0 | 0
2 |  | 85 | 0
3 |  | 70 | 23.6
4 |  | 66 | 23.8
5 |  | 0 | 24
6 |  | 61 | 24.1
7 |  | 60 | 24.3

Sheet: Sheet4
B | Flat | stetch | bench
0 | 2.3
1 |  | 3.2 | 0
2 |  | 0 | 2.04
3 |  | 2.91 | 0
4 |  | 0 | 2.08
5 |  | 2.76 | 0
6 |  | 0 | 2.15
7 |  | 2.7 | 0
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

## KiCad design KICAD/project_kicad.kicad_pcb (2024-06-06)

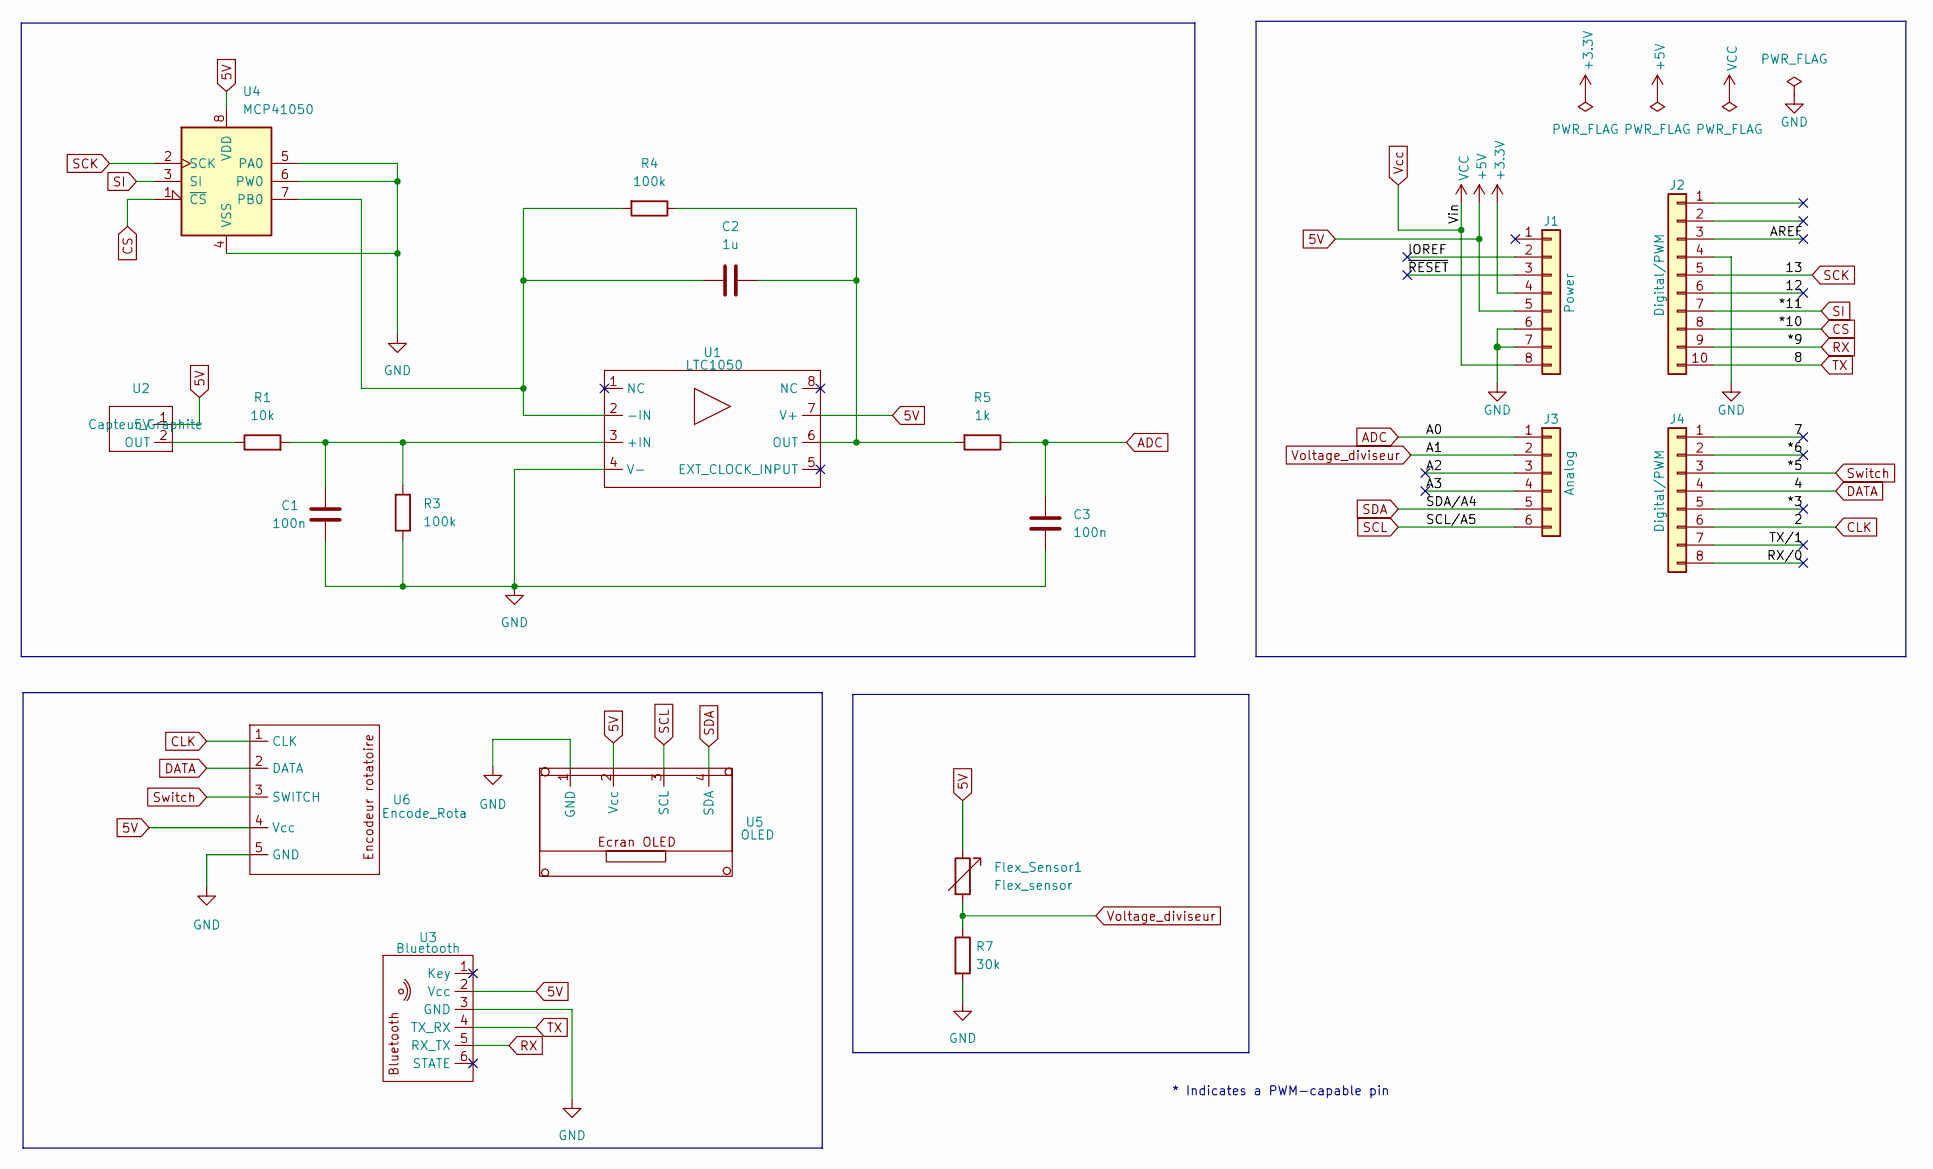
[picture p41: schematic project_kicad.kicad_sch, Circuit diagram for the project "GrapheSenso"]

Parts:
C1, C3: 100n; CP_Radial_Tantal_D5.5mm_P2.50mm
C2: 1u; C_Rect_L7.0mm_W4.5mm_P5.00mm
Flex_Sensor1: Flex_sensor; Flex
J1: Power; PinSocket_1x08_P2.54mm_Vertical
J2: Digital/PWM; PinSocket_1x10_P2.54mm_Vertical
J3: Analog; PinSocket_1x06_P2.54mm_Vertical
J4: Digital/PWM; PinSocket_1x08_P2.54mm_Vertical
R1: 10k; R_Axial_DIN0204_L3.6mm_D1.6mm_P5.08mm_Horizontal
R3, R4: 100k; R_Axial_DIN0204_L3.6mm_D1.6mm_P5.08mm_Horizontal
R5: 1k; R_Axial_DIN0204_L3.6mm_D1.6mm_P5.08mm_Horizontal
R7: 30k; R_Axial_DIN0204_L3.6mm_D1.6mm_P5.08mm_Horizontal
U1: LTC1050
U2: Capteur_Graphite; Capteur Graphite
U3: Bluetooth; Bluetooth HC05-20
U4: MCP41050; Pot_Digital
U5: OLED; Ecran OLED
U6: Encode_Rota; Encodeur rotatoire

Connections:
5V: Flex_Sensor1.1, J1.5, U1.7 (V+), U2.1 (5V), U3.2 (Vcc), U4.8 (VDD), U5.2 (Vcc), U6.4 (Vcc)
+3V3: J1.4
/7: J4.1
/12: J2.6
/*3: J4.5
/*6: J4.2
/A2: J3.3
/A3: J3.4
/AREF: J2.3
/IOREF: J1.2
/RX/0: J4.8
/TX/1: J4.7
/~RESET: J1.3
ADC: C3.2, J3.1, R5.1
CLK: J4.6, U6.1 (CLK)
CS: J2.8, U4.1 (~CS)
DATA: J4.4, U6.2 (DATA)
GND: C1.1, C3.1, J1.6, J1.7, J2.4, R3.1, R7.2, U1.4 (V-), U3.3 (GND), U4.4 (VSS), U4.5 (PA0), U4.6 (PW0), U5.1 (GND), U6.5 (GND)
unnamed: C1.2, R1.2, R3.2, U1.3 (+IN)
unnamed: C2.2, R4.2, U1.2 (-IN), U4.7 (PB0)
unnamed: C2.1, R4.1, R5.2, U1.6 (OUT)
unnamed: R1.1, U2.2 (OUT)
RX: J2.9, U3.5 (RX_TX)
SCK: J2.5, U4.2 (SCK)
SCL: J3.6, U5.3 (SCL)
SDA: J3.5, U5.4 (SDA)
SI: J2.7, U4.3 (SI)
Switch: J4.3, U6.3 (SWITCH)
TX: J2.10, U3.4 (TX_RX)
Vcc: J1.8
Voltage_diviseur: Flex_Sensor1.2, J3.2, R7.1

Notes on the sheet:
* Indicates a PWM-capable pin

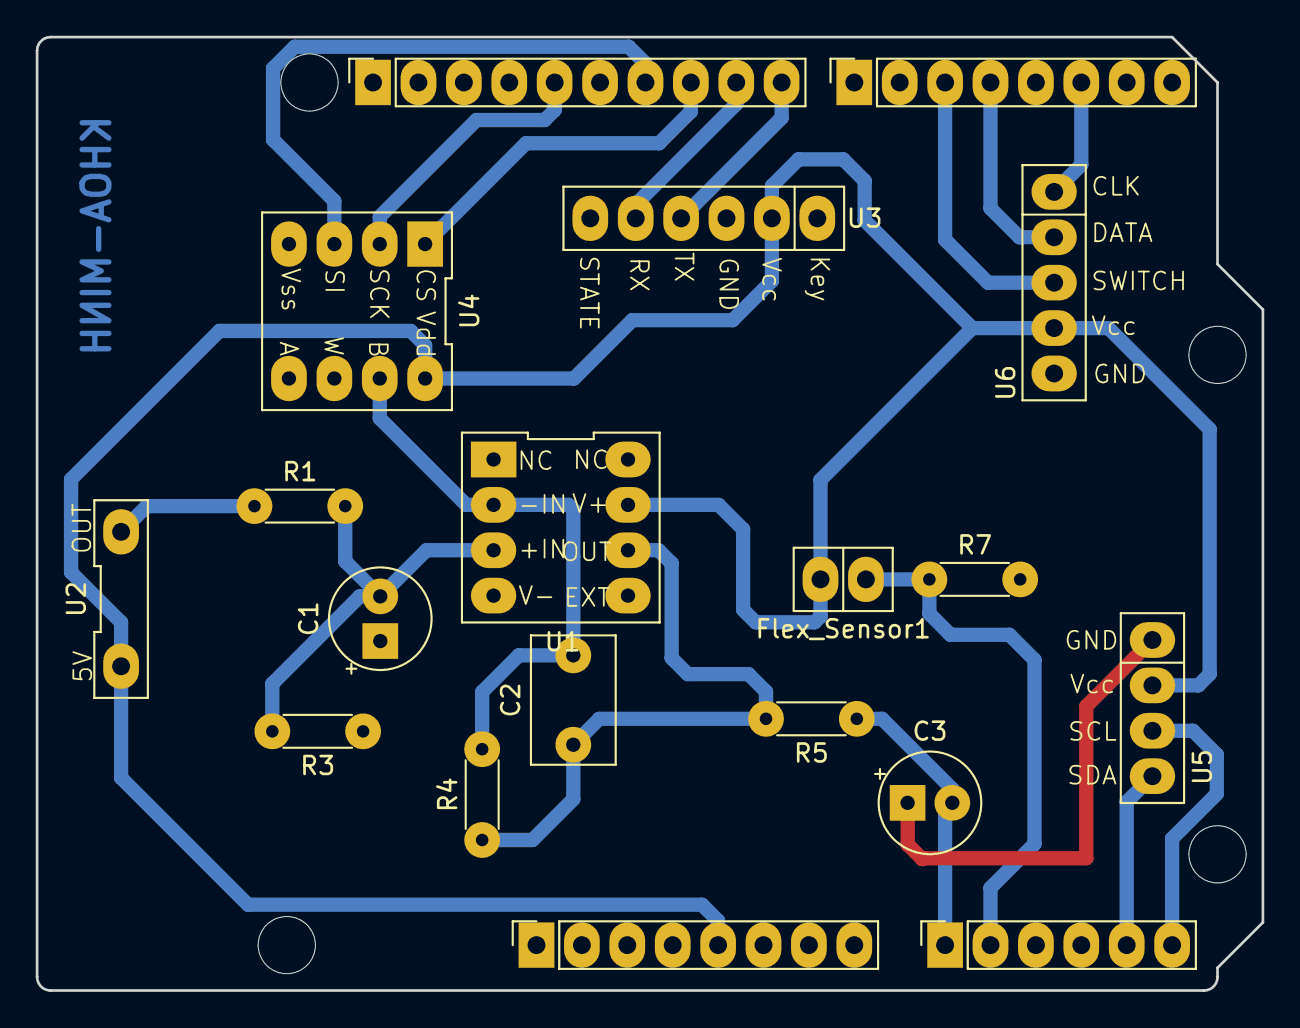
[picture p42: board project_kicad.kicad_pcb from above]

Board: 2 copper layers, 68.6 x 53.3 mm, 23 parts (0 on the bottom side), 18 nets.

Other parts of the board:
MH1, MH2, MH3, MH4: MountingHole_3.2mm

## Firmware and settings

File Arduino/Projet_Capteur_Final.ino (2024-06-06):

/*
  Fichier :       afficherTexteSsd1306.ino
  Description :   Affiche du texte de test, sur un écran OLED i2c de 128x64 pixels,
                  fonctionnant avec un contrôleur SSD1306
  Auteur :        Jérôme TOMSKI (https://passionelectronique.fr/)
  Créé le :       26.07.2021
*/
#include <SPI.h>
#include <Adafruit_SSD1306.h>
#include <SoftwareSerial.h>


#define rxPin 8 //Broche 11 en tant que RX, � raccorder sur TX du HC-05
#define txPin 9 //Broche 10 en tant que RX, � raccorder sur TX du HC-05
#define Clock 200 //Horloge pour cadancer l'envoie du data vers module Bluetooth
                  //Merci de mettre cette valeur (en ms) >= 2 fois la valeur du timer d'appli BT


#define nombreDePixelsEnLargeur 128         // Taille de l'écran OLED, en pixel, au niveau de sa largeur
#define nombreDePixelsEnHauteur 64          // Taille de l'écran OLED, en pixel, au niveau de sa hauteur
#define brocheResetOLED         -1          // Reset de l'OLED partagé avec l'Arduino (d'où la valeur à -1, et non un numéro de pin)
#define adresseI2CecranOLED     0x3C        // Adresse de "mon" écran OLED sur le bus i2c (généralement égal à 0x3C ou 0x3D)
// Define the MCP41100 OP command bits (only one POT)
// Note: command byte format xxCCxxPP, CC command, PP pot number (01 if selected) 
#define MCP_NOP 0b00000000
#define MCP_WRITE 0b00010001
#define MCP_SHTDWN 0b00100001

#define encoder0PinA  2  //CLK Output A Do not use other pin for clock as we are using interrupt
#define encoder0PinB  4  //DT Output B
#define Switch 5 // Switch connection if available


const int ssMCPin = 10; // Define the slave select for the digital pot

Adafruit_SSD1306 ecranOLED(nombreDePixelsEnLargeur, nombreDePixelsEnHauteur, &Wire, brocheResetOLED);//Initialiser ecran OLED

const int flexPin = A1;      // Pin connected to voltage divider output

// Change these constants according to your project's design
const float VCC = 5;      // voltage at Ardunio 5V line
const float R_DIV = 33000.0;  // resistor used to create a voltage divider
const float flatResistance = 25000.0; // resistance when flat
const float bendResistance = 100000.0;  // resistance at 90 deg

volatile float R2; //Valeur de la resistance R2
volatile float Gain;//Valeur du gain du montage

volatile int R2_index = 10;   //indice a envoyer au potentionmetre digital
unsigned long t = 0;          //Variable temporelle pour l'envoi de la valeur resistance au module BT
unsigned long t_etoile = 0;       //Variable temporelle pour l'envoi de l'indice gaphite/flex au module BT

volatile int Capteur_ou_flex = 1;     //Indice a determiner si la mesure est sur graphite ou flex 

volatile unsigned int encoder0Pos = 0; //Initialiser la valeur du encoder rotatoire, defaut = 0 correspondant a la mesure sur capteur graphite

SoftwareSerial mySerial(rxPin ,txPin); //Definition du software serial


void SPIWrite(uint8_t cmd, uint8_t data, uint8_t ssPin) // SPI write the command and data to the MCP IC connected to the ssPin
{
  SPI.beginTransaction(SPISettings(14000000, MSBFIRST, SPI_MODE0)); //https://www.arduino.cc/en/Reference/SPISettings
  
  digitalWrite(ssPin, LOW); // SS pin low to select chip
  
  SPI.transfer(cmd);        // Send command code
  SPI.transfer(data);       // Send associated value
  
  digitalWrite(ssPin, HIGH);// SS pin high to de-select chip
  SPI.endTransaction();
}


void setup() {
  // Initialisation Serial, etat des pins
  Serial.begin(9600);
  mySerial.begin(9600);
  pinMode(rxPin,INPUT);
  pinMode(txPin,OUTPUT);
  pinMode(flexPin, INPUT);

  // Initialisation de l'écran OLED
  ecranOLED.begin(SSD1306_SWITCHCAPVCC, adresseI2CecranOLED);

  byte tailleDeCaractere=1;
  boolean bCouleurInverse = false;
  ecranOLED.clearDisplay();                                   // Effaçage de l'intégralité du buffer
  ecranOLED.setTextSize(tailleDeCaractere);                   // Taille des caractères (1:1)
  ecranOLED.setCursor(0, 0);                                  // Déplacement du curseur en position (0,0), c'est à dire dans l'angle supérieur gauche
  ecranOLED.setTextColor(SSD1306_WHITE);                  // Affichage du texte en "blanc" (avec la couleur principale, en fait, car l'écran monochrome peut être coloré)

  pinMode (ssMCPin, OUTPUT); //select pin output
  digitalWrite(ssMCPin, HIGH); //SPI chip disabled
  SPI.begin(); 
  Serial.println(F("[MCP Digital Pot Test]")); //print to serial

  pinMode(encoder0PinA, INPUT); 
  digitalWrite(encoder0PinA, HIGH);       // turn on pullup resistor

  pinMode(encoder0PinB, INPUT); 
  digitalWrite(encoder0PinB, HIGH);       // turn on pullup resistor

  attachInterrupt(0, doEncoder, RISING); // encoder pin on interrupt 0 - pin2
  SPIWrite(MCP_WRITE, R2_index, ssMCPin); //envoyer data a potention metre digital

}

void loop() {

  int value_to_bluetooth; // Valeur a envoyer au module BT (flex ou sensor graphite)
  // Read the ADC, and calculate voltage and resistance from it
  int ADCflex = analogRead(flexPin); //Lire la valeur du flex sensor
  float Vflex = ADCflex * VCC / 1023.0; //Convertir la valeur lue sur l'arduino en mV
  float Rflex = (R_DIV * (VCC / Vflex - 1.0))/1000; //Calcul de la resistance du flex sensor 

  // Use the calculated resistance to estimate the sensor's bend angle:
  float angle = map(Rflex, flatResistance, bendResistance, 0, 90.0);
  
  while (mySerial.available()) {
		R2_index = (int)mySerial.read();  // indice pour le potentionmetre digital envoye via module BT
    SPIWrite(MCP_WRITE, R2_index, ssMCPin); //envoyer data a potention metre digital

	}

  R2 = 50000*R2_index/256 + 52; // Calcul de la resistance du potentionmetre digital

  Gain = 1+100000/R2; //Calcul du Gain

    // read the input on analog pin 0:
  int sensorValue = analogRead(A0);
  float VGraphite = (sensorValue+1) * VCC / 1024.0; //Convertir la valeur lue sur l'arduino en mV
  float RGraphite = (Gain*500000/VGraphite - 110000)/1000; //Calcul de la resistance de la capteur graphite

  //Commencer l'affichage sur ecran OLED
  ecranOLED.clearDisplay();
  ecranOLED.setCursor(0, 0); 

  //l'indice capteur_ou_flex indique sur quel capteur les mesures sont faites
  //Si Capteur_ou_flex == 1, les mesure sont sur capteur graphite et si Capteur_ou_flex == 0, les mesures sont sur flex sensor
  if(Capteur_ou_flex == 1){

    ecranOLED.print("A0 Read Valeur: ");
    ecranOLED.println(sensorValue);
    ecranOLED.println();

    ecranOLED.print("Graphite resistance: ");
    ecranOLED.print(RGraphite);
    ecranOLED.print(" kOhms");
    ecranOLED.println();
    
    ecranOLED.println();

    ecranOLED.print("Gain:");
    ecranOLED.print(Gain);
    ecranOLED.println();
    //Valeur a envoyer au module BT
    value_to_bluetooth = sensorValue;
  }

  if(Capteur_ou_flex == 0){
    
    ecranOLED.print("A1 Read Valeur: ");
    ecranOLED.println(ADCflex);
    ecranOLED.println();

    ecranOLED.print("Flex sensor resistance: ");
    ecranOLED.print(Rflex);
    ecranOLED.print(" kOhms");
    ecranOLED.println();

    //Valeur a envoyer au module BT
    value_to_bluetooth = ADCflex;
  }

  //Afficher la resistance R2 du potentionmetre digital
  ecranOLED.println();
  ecranOLED.print("R2 = ");
  ecranOLED.print(R2);

  ecranOLED.display();

  //Envoyer le data au module BT, ici on envoie 2 bytes(65,535 valeurs possibles) pour garder la resolution de mesure (1024 valeurs)
  if (abs(millis()-t) > Clock){    //Cadancer la periode a envoyer au module BT
    t=millis();
    //convertir la valeur lue dans 2 byte a envoyer au module BT  
    byte byte1st = value_to_bluetooth / 256;      
    byte byte2nd = value_to_bluetooth % 256;      
    //Envoyer 2 bytes au module BT
    mySerial.write(byte2nd);       
    delay(3);
    mySerial.write(byte1st);
    delay(3);
  }


  delay(100);  // delay in between reads for stability
}

//doEncoder permet de changer mecaniquement sur quel capteur on fait les mesures. 
//Ici, on code un nombre quelconque different aux valeurs possibles des mesures.
//La valeur des mesure est contenue dans [0,1023] => l'indice doit etre en dehors de cette intervale.
//On code 4096 indiquant le flex sensor et 2048 indiquant le capteur graphite.
void doEncoder() {
  if (digitalRead(encoder0PinB)==HIGH) {
    Capteur_ou_flex =1;  

    if (abs(millis()-t_etoile) > 500){              //Each data sent to module BT only occur after 0,5s to ensure the stability    
    t_etoile=millis();                              //because the interruption is cadanced by a mechanical clock which is not stable 
    byte graphite_flex1st = 4096 / 256;       //Convertir indice codee en 2 byte  
    byte graphite_flex2nd = 4096 % 256; 

    mySerial.write(graphite_flex2nd);
    delay(3);
    mySerial.write(graphite_flex1st);
    delay(3);
    }


    }
  else {
    Capteur_ou_flex=0;
    if (abs(millis()-t_etoile) > 500){                                
    t_etoile=millis();
    byte graphite_flex1st = 2048 / 256;             //convertir indice codee en 2 byte   
    byte graphite_flex2nd = 2048 % 256; 

    mySerial.write(graphite_flex2nd);
    delay(3);
    mySerial.write(graphite_flex1st);
    delay(3);
    }

    }
  }
